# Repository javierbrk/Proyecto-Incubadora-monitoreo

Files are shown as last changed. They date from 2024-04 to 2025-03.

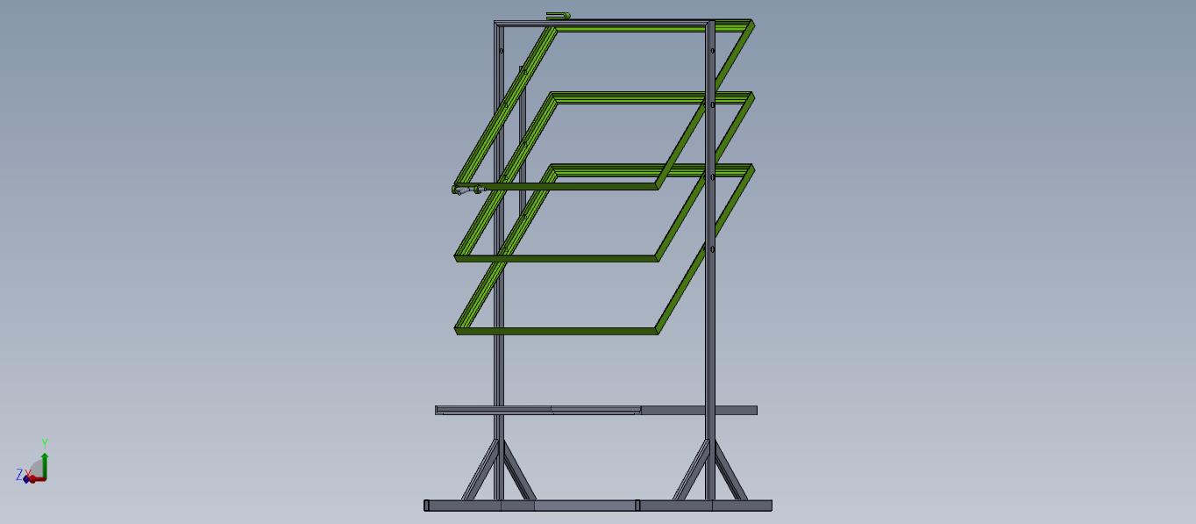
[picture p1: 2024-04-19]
HardWare/ModelosMecanica/SistemaBasculante.jpg

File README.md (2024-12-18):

# LibrePollo

Is an innovative project aimed at enhancing the efficiency and productivity of poultry incubators in family farming. Developed by Asociación Civil AlterMundi and CTO, this system integrates advanced monitoring and control technologies to optimize temperature and humidity levels, reducing manual labor and increasing hatch rates. Utilizing free hardware and software, the project promotes sustainable agricultural practices and empowers local communities with technical skills. Join us in revolutionizing family farming with technology!

## made with :heart: by:

<p align="center" width="100%">
    
</p>

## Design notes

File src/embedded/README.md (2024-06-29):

# Project-Incubadora Software

## Notes before you start :raised_back_of_hand:

 add the current user to the dialout group. This will allow us to use the USB directly

```bash
sudo usermod -a -G dialout $USER
```
We also add ourselves to the group temporarily so we don't have to log in to the system again. If we do not, it will be necessary to restart for the changes to take effect.

```bash
newgrp dialout
```

if you are usign ubuntu 22 and the esp32cam motherboard based on "ID 1a86:7523 QinHeng Electronics CH340 serial converter" you won't be able to use the device. This happens because of conflict between product IDs (a Braille screen reader and my CH340 based chip). Here is the solution :

Edit /usr/lib/udev/rules.d/85-brltty.rules; Search for this line and comment it out:

```bash
ENV{PRODUCT}=="1a86/7523/*", ENV{BRLTTY_BRAILLE_DRIVER}="bm", GOTO="brltty_usb_run"
```

then reboot.

## Firmware with lua support

 clone the repository

```bash
git clone --branch dev-esp32 --depth=1 --shallow-submodules --recurse-submodules https://github.com/nodemcu/nodemcu-firmware.git firmwareESP32 
```
 Once cloned enter the downloaded file with:

```bash
 cd firmwareESP32
```
then download the sdkmanager file to be able to compile the firmware:

```bash
 wget -c https://cutt.ly/QwjY9Sdt --output-document sdkconfig --show-progress
```
```bash
git pull
```
```bash
./install.sh
```
```bash
make menuconfig  
```

```bash
make -j4  
```

## Burn Firmware with ESPTool

__Installation of ESPTool__

```bash
sudo apt install esptool
```

Put the ESP32 in programming mode by holding the IO0 button and pressing the RST button at the same time.

from the 'build' folder run:

```bash
esptool --chip esp32 --port /dev/ttyUSB0 --baud 921600 --before default_reset --after hard_reset write_flash -z --flash_mode dio --flash_freq 80m --flash_size detect 0x1000 bootloader/bootloader.bin 0x10000 NodeMCU.bin 0x8000 partitions.bin
```
or
```bash
make flash
```

## Load the Lua scripts

To load the scripts we have 2 options:
* [EspLorer](https://github.com/4refr0nt/ESPlorer)
* [nodemcu-uploader](https://pypi.org/project/nodemcu-uploader/)

## Editing Lua scripts
* [ZeroBrane](https://studio.zerobrane.com/)
* VSCodium... remember to install sumneko's Lua package, then using the open addon manager install esp32 definitions. 

## Option 1 (ESPlorer, must be latest version)
* [Link to git and readme for the latest version of ESPlorer](https://github.com/4refr0nt/ESPlorer)

 clone the repository:

```bash
git clone https://github.com/4refr0nt/ESPlorer.git
```
after cloning it:

```bash
cd ESPlorer
./mvnw clean package
```
to execute ESPlorer:

```bash
java -jar target/ESPlorer.jar
```

## Option 2 (nodemcu-uploader)

installation:

```bash
sudo pip install nodemcu-uploader
```
once installed, we can upload files using:

```bash
nodemcu-uploader upload init.lua
```

to see the different commands that can be used:
```bash
nodemcu-uploader -h
```

## Option 3 (ZeroBraneStudio)

installation:
```bash
wget https://download.zerobrane.com/ZeroBraneStudioEduPack-1.90-linux.sh
```
After downloading, we give it execution permission with:

```bash
chmod +x ZeroBraneStudioEduPack-1.90-linux.sh
```
after giving it permissions, run the installer:

```bash
./ZeroBraneStudioEduPack-1.90-linux.sh
```

## Useful Links

* [Pad incubadora](https://pad.codigosur.org/AM_Proyecto_Incubadora)
* [Sensor information BME280](https://3iinc.xyz/blog/how-to-use-i2c-sensor-bme280-with-esp32cam/)
* [Documentation nodemcu](https://nodemcu.readthedocs.io/en/dev-esp32)
* [Repository with modules Lua](https://github.com/novalabsxyz/api-examples/blob/master/script/bme280/bme280.lua)
* [Sensor information DHT22](https://nodemcu.readthedocs.io/en/dev-esp32/modules/dht/#dhtread2x)
* [Git Tutorials](https://rogerdudler.github.io/git-guide/index.es.html )
* [Files and photos](https://nube.altermundi.net/s/3arPqaHxs763pmB?path=%2F)

## files we need to send to the ESP32

1. bmw280.lua located in the libs folder 
2. credentials.lua located in the libs folder (in lines 5 and 6 you have to write your SSID and password)
3. wifiinit.lua located in the app folder 
4. SendToGrafana.lua located in the app folder

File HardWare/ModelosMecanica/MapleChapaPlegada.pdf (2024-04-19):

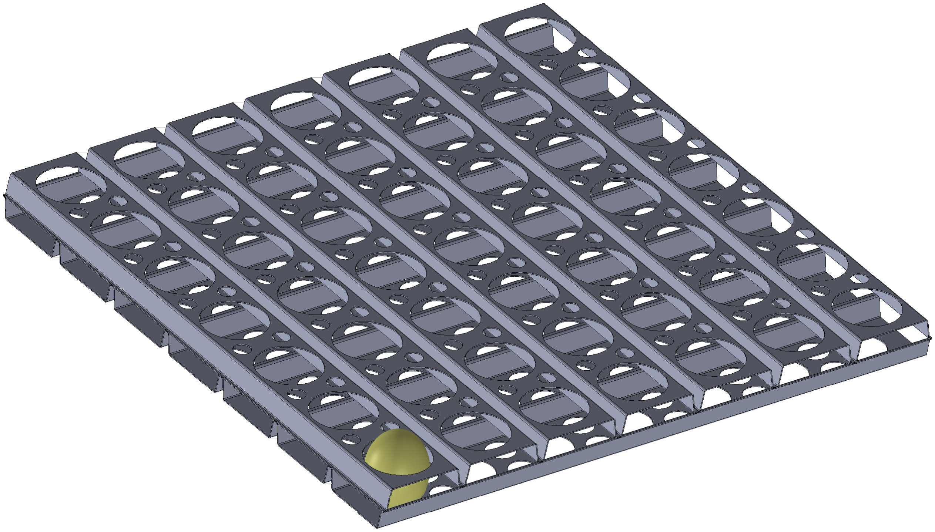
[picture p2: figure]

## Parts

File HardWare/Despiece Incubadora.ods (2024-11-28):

módulo | item | cantidad por incu | enlace
Electronica electriciad
 | 1 Enchufe macho | 1 | https://articulo.mercadolibre.com.ar/MLA-1508200684-pack-x10-enchufe-ficha-macho-10a-3-patas-negro-_JM |  | 7700 | 7700
 | 2m + 1m cable TPR 3 x 2,5mm | 3
 | 2 Prensa-cables 10mm | 2 | https://articulo.mercadolibre.com.ar/MLA-1127213017-pack-x10-prensacable-diametro-cable-5-10mm-ip68-pg11-34-_JM |  | 8.804 | 8.804
 | 1 Disyuntor diferencial 16A (https://www.mercadolibre.com.ar/disyuntor-diferencial-bipolar-16a-2x16a-10ma-usensible-sica/p/MLA10763521) | 1 | https://www.mercadolibre.com.ar/disyuntor-diferencial-2x25-sica-bipolar-monofasico/p/MLA21622049 | https://www.mercadolibre.com.ar/disyuntor-diferencial-bipolar-16a-2x16a-10ma-usensible-sica/p/MLA10763522 | 23000 | 23000
 | Alimentación barril a PCB (https://tienda.ityt.com.ar/plug-alimentacion/3471-lote-10-x-plug-dc-55x21mm-conector-alimentaci%C3%B3n-itytarg.html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) | 1 |  |  |  | 0
 | Térmica 5A (https://www.mercadolibre.com.ar/interruptor-automatico-miniatura-para-riel-din-sica-limit-782105/p/MLA11259424) | 1 | https://www.mercadolibre.com.ar/interruptor-automatico-miniatura-para-riel-din-sica-limit-782105/p/MLA11259424 |  | 2500 | 2500
 | Térmica 1 A (https://www.mercadolibre.com.ar/interruptor-automatico-miniatura-para-riel-din-sica-limit-782105/p/MLA11259424) | 2 | https://articulo.mercadolibre.com.ar/MLA-1410464619-termica-unipolar-termomagnetica-1a-1x1-sica-782101-_JM | https://articulo.mercadolibre.com.ar/MLA-1364995926-termica-unipolar-termomagnetica-1a-1x1-sica-782101-_JM | 4000 | 8000
 | PCB Olivia | 1
 | Fuente 12V 5A (https://articulo.mercadolibre.com.ar/MLA-1948645246-fuente-metalica-de-alimentacion-12-v-5a-_JM) | 1 | https://articulo.mercadolibre.com.ar/MLA-1948645246-fuente-metalica-de-alimentacion-12-v-5a-_JM |  | 7000 | 7000
 | Step-Down 6V (https://articulo.mercadolibre.com.ar/MLA-723761124-fuente-step-down-dc-dc-lm2596-125v-35v-3a-arduino-nubbeo-_JM) | 1 | https://articulo.mercadolibre.com.ar/MLA-723761124-fuente-step-down-dc-dc-lm2596-125v-35v-3a-arduino-nubbeo-_JM |  |  | 0
Conexiones | Alimentación Step-down 6v a PuenteH y Relé | 1
Conexiones | Sensor BME280 (4pin) (https://articulo.mercadolibre.com.ar/MLA-818527025-sensor-modulo-arduino-bme280-temperatura-humedad-presion-_JM) | 1
Conexiones | FC Up (2pin) | 1
Conexiones | FC Down (2pin) | 1
Conexiones | PuenteH (4 pin) | 1
Conexiones | Módulo Relé (3pin) | 1
 | Cablecanal (https://articulo.mercadolibre.com.ar/MLA-918107217-cable-canal-autoadhesivo-taad-20x10-x-10-mts-_JM) | 1 | https://articulo.mercadolibre.com.ar/MLA-918107217-cable-canal-autoadhesivo-taad-20x10-x-10-mts-_JM |  |  | 0
 | CAJA Estanco (https://www.mercadolibre.com.ar/caja-estanca-plastica-210x310x110-mm-blanca-ip65-color-blanco/p/MLA26881998) | 1 | https://www.mercadolibre.com.ar/caja-estanca-plastica-210x310x110-mm-blanca-ip65-color-blanco/p/MLA26881998 |  | 16000 | 16000
 | Puente H | 1
 | Regleta neutros | 1 | https://articulo.mercadolibre.com.ar/MLA-1213323854-pack-x6-bornera-distrib-repartidor-fase-neutra-tierra-7x6mm-_JM |  |  | 0
 | Interruptor Iluminación | 1
 | Sensor BME280 (https://articulo.mercadolibre.com.ar/MLA-818527025-sensor-modulo-arduino-bme280-temperatura-humedad-presion-_JM) | 1 | https://articulo.mercadolibre.com.ar/MLA-818527025-sensor-modulo-arduino-bme280-temperatura-humedad-presion-_JM |  | 10300 | 10300
Humedad |  |  |  |  |  | 0
 | bomba de nafta | 8 | https://articulo.mercadolibre.com.ar/MLA-1662031398-bomba-de-nafta-tbosch-corsa-meriva-gol-suran-siena-fiat-uno-_JM |  | 17000 | 136000
 | picos asperción x 3 | 3 | https://listado.mercadolibre.com.ar/pico-metalico_CustId_7317189_NoIndex_True |  | 32000 | 96000
 | acoples rápido | 8 | https://articulo.mercadolibre.com.ar/MLA-906924217-conector-rapido-neumatico-recto-tubo-tubo-de-6-mm-a-8-mm-_JM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 |  | 3560 | 28480
 | Budineras | 8 | https://articulo.mercadolibre.com.ar/MLA-849023158-budinera-budin-ingles-flanera-aluminio-34cm-pettish-online-_JM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 |  | 10000 | 80000
 | alumnio 3mm | 8 |  |  |  | 0
 | espiga | 8 |  |  |  | 0
 | yerbera
 | manguera 8mm
 | salida de tanque | 8 |  |  |  | 0
 | Flotante | 8 | https://articulo.mercadolibre.com.ar/MLA-1313921621-flotante-compacto-tanque-agua-12-flux-_JM?quantity=4 |  | 9000 | 72000
Rotación |  |  |  |  |  | 0
 | Estructura hierro |  |  |  |  | 0
 | anclajes a la estructura (bulon pasante con dos tuercas para regular la distancia y tornillos para )
 | Bulones pasantes
 | Motor
 | soporte 3d motor, soporte, polea
 | Contrapeso
 | Cinta gross
 | sensores | 16 | https://articulo.mercadolibre.com.ar/MLA-878544727-sensor-magnetico-para-alarma-puerta-y-ventana-seguridad-_JM |  | 3000 | 48000
Accesorios |  |  |  |  |  | 0
 | resistencia | 8 | https://articulo.mercadolibre.com.ar/MLA-913198984-resistencia-para-incubadora-de-huevos-electrica-200w-220v-_JM |  | 140000 | 1120000
 | Luz | 7 | https://articulo.mercadolibre.com.ar/MLA-862597264-reflector-led-10w-luz-fria-apto-exterior-800lm-_JM |  | 3200 | 22400
 | L para el ventilador |  |  |  |  | 0
 | ventilador | 8 | https://articulo.mercadolibre.com.ar/MLA-603230889-turbina-cooler-extractor-fan-220v-ruleman-6-pulgadas-_JM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 |  | 29000 | 232000
 | Bandejas hueveras | 30 |  |  | 4000 | 120000
 | Bandejas nacedoras | 8 |  |  | 2000 | 16000
 | maples plásticos | 60 |  |  | 4000 | 240000
 | sunchos |  |  |  |  | 0
 | tejido alambre | 20 |  |  | 15909 | 318180
Carcasa |  |  |  |  |  | 2539360
 | Placas
 | pintura
 | sellador y pegamento
 | tornillos
 | perfilería aluminio
 | Bisagras
 | tarugos, tornillos y otros
 | patas
 | Bisagras
 | Ventana vertical
 | Patas de goma/esquinero

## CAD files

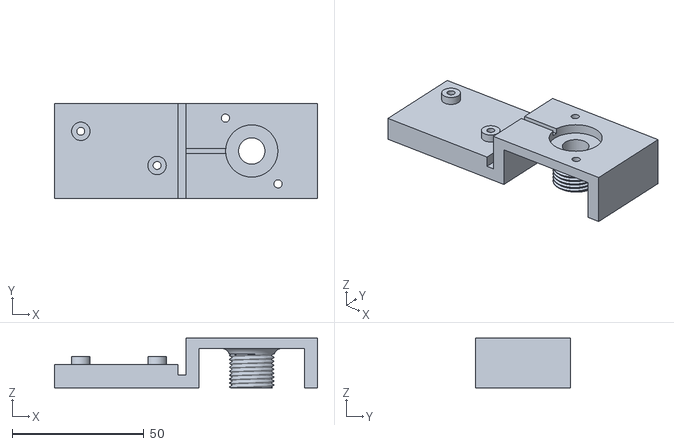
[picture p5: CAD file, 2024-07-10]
HardWare/modelos3D/humidificador/estructura_principal_humidificador.stl
100.0 x 36.0 x 19.0

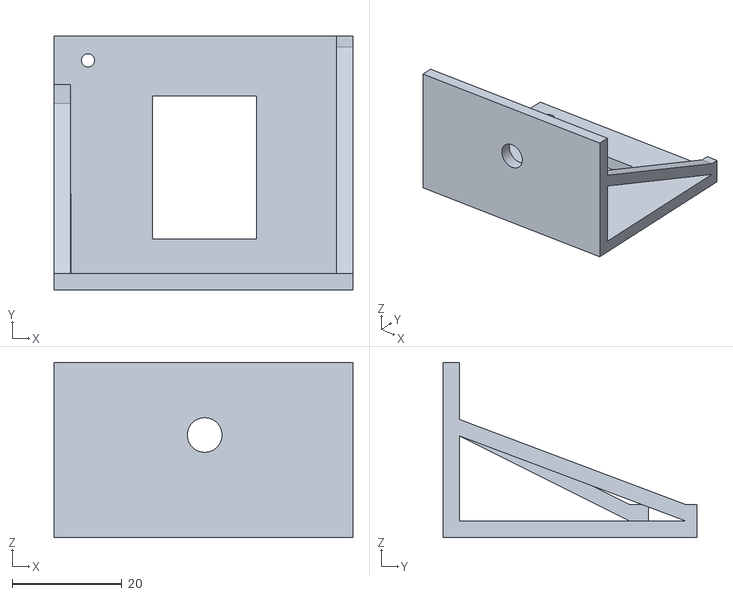
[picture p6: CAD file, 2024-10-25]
HardWare/modelos3D/rotacion/CarcasaPolea_conColumnas.stl
54.5 x 46.3 x 31.9

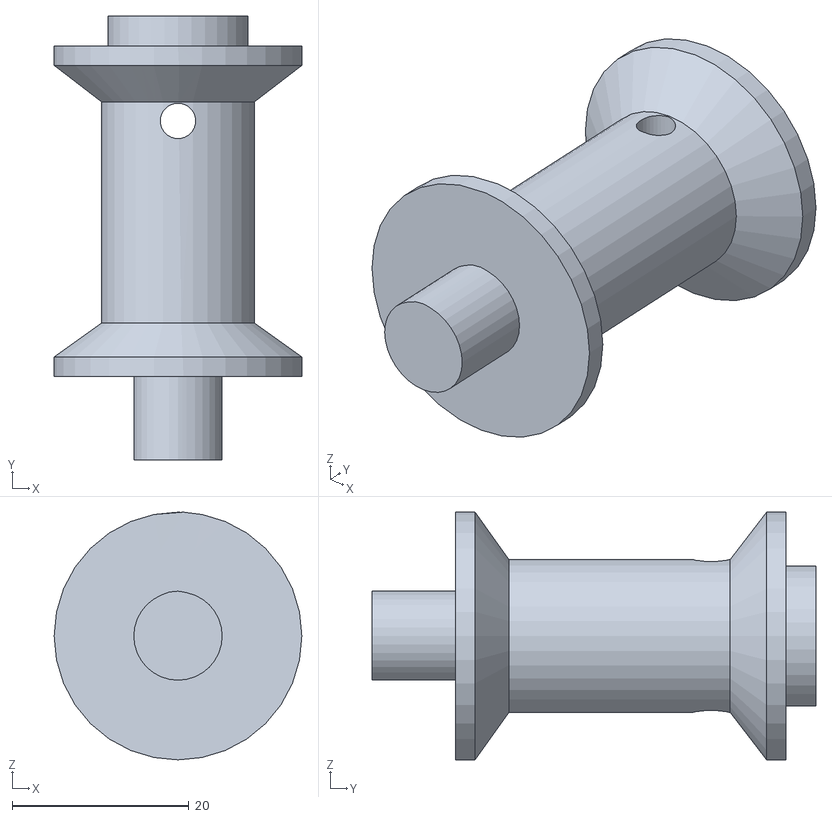
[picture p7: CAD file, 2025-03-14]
HardWare/modelos3D/rotacion/modelos-finales/Polea.stl
28.1 x 50.3 x 28.1

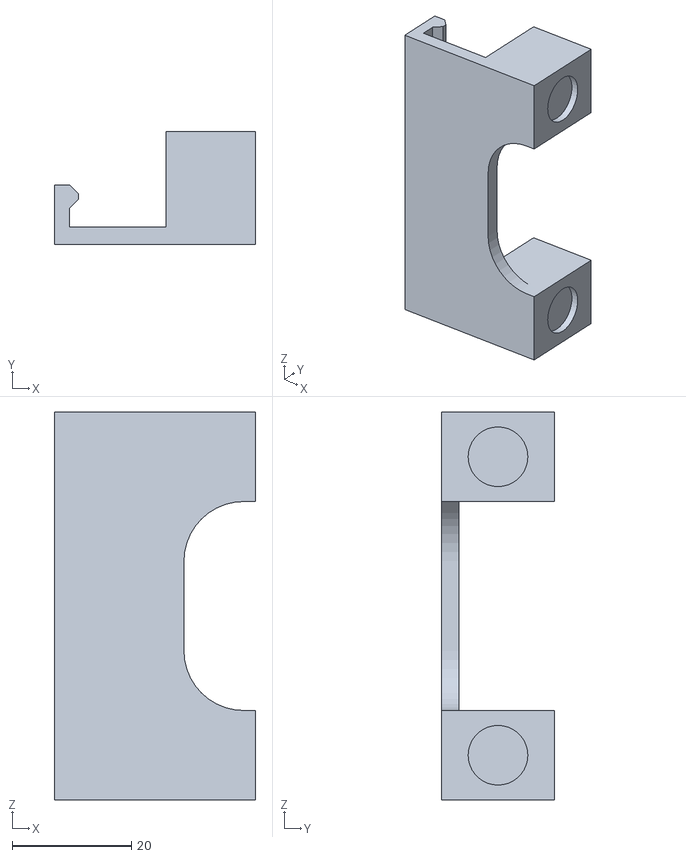
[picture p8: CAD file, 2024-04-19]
HardWare/modelos3D/SoporteIman.STL
33.7 x 19.0 x 65.0

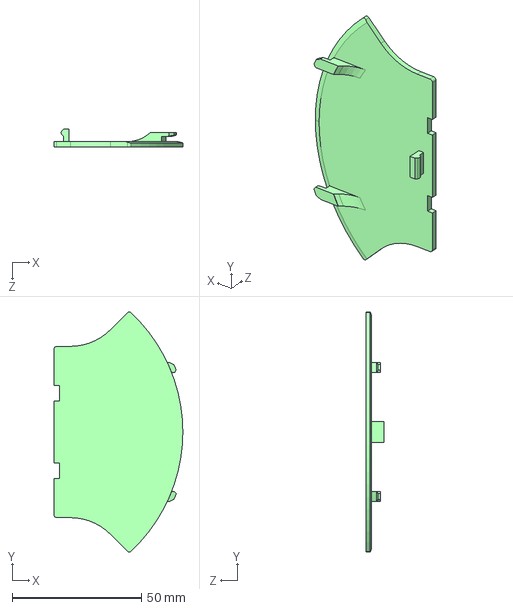
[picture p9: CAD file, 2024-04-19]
HardWare/ModelosMecanica/EnSTEP/SoporteEfectoHallTapa.STEP
49.9 x 93.0 x 6.80 mm

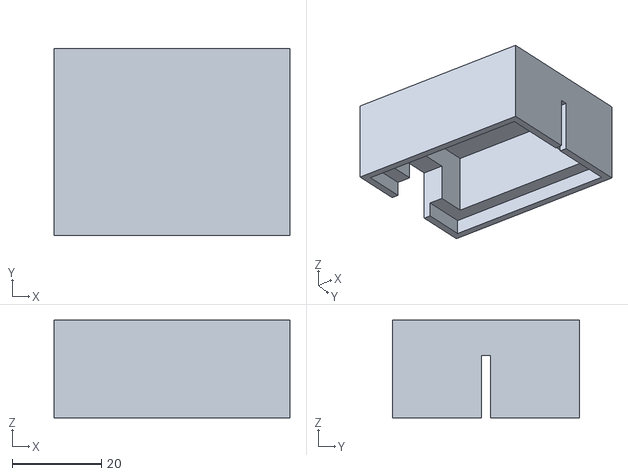
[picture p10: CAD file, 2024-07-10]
HardWare/modelos3D/humidificador/caja_protectora_humidificador.stl
53.0 x 42.0 x 22.0

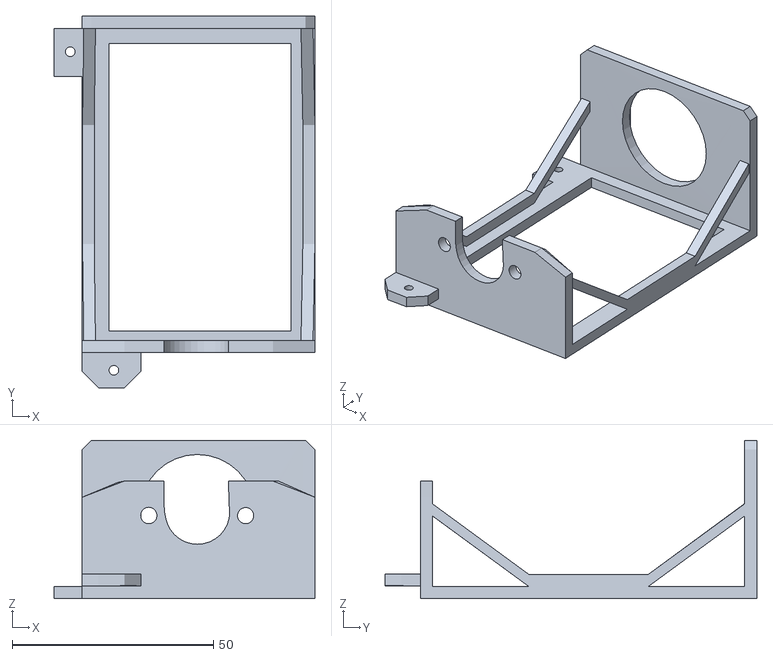
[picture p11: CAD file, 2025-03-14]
HardWare/modelos3D/rotacion/modelos-finales/SoporteMotor.stl
64.8 x 92.4 x 39.4

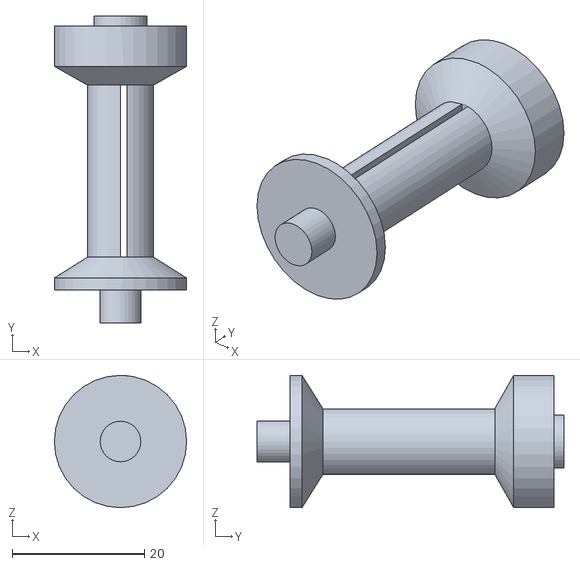
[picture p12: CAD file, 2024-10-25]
HardWare/modelos3D/rotacion/SoportePoleaNuevo.stl
20.0 x 46.5 x 20.0

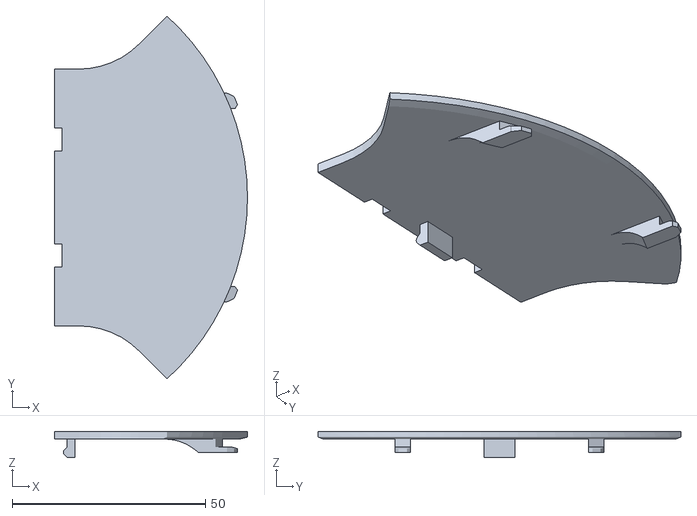
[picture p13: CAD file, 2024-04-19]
HardWare/modelos3D/SoporteEfectoHallTapa.STL
49.9 x 93.8 x 6.80

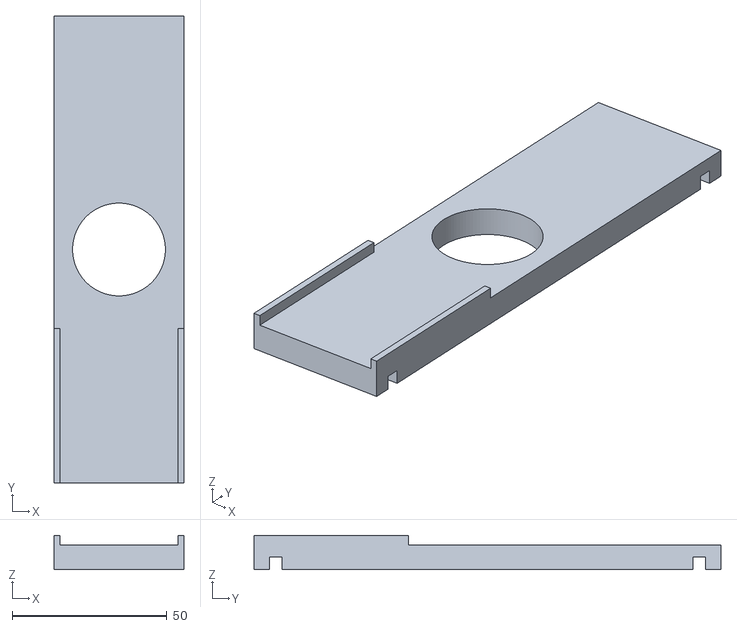
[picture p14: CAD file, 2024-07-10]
HardWare/modelos3D/humidificador/soporte_humidificador.stl
42.0 x 151.0 x 11.0

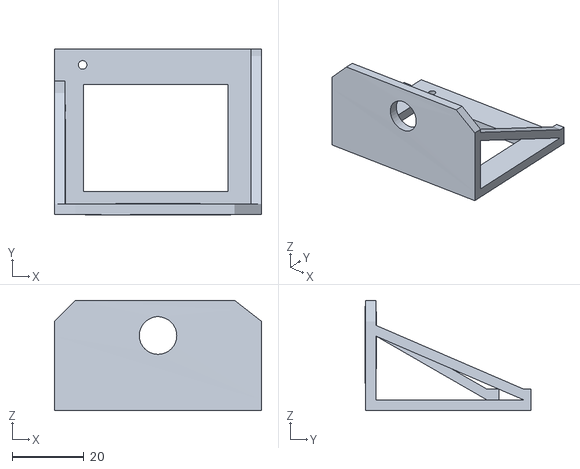
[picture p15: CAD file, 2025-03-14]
HardWare/modelos3D/rotacion/modelos-finales/SoportePolea.stl
57.8 x 46.3 x 30.8

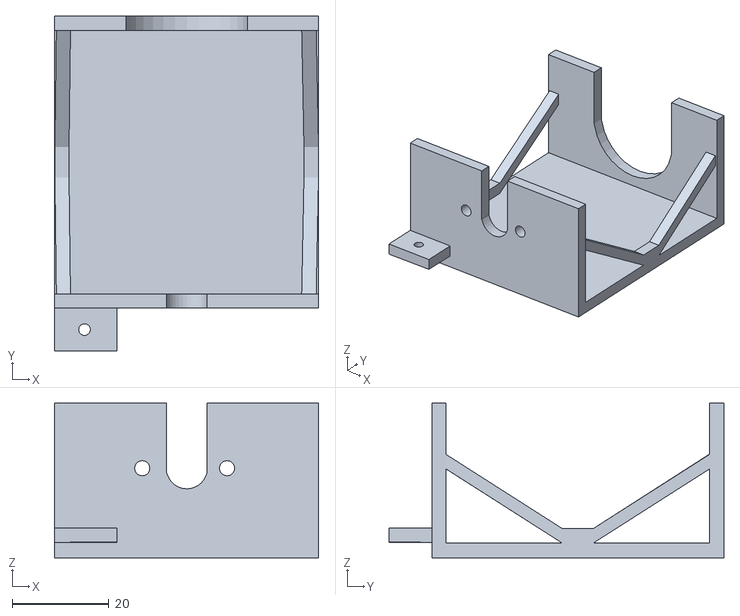
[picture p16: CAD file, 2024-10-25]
HardWare/modelos3D/rotacion/SoporteMotorConTriangulos.stl
54.5 x 69.1 x 31.9

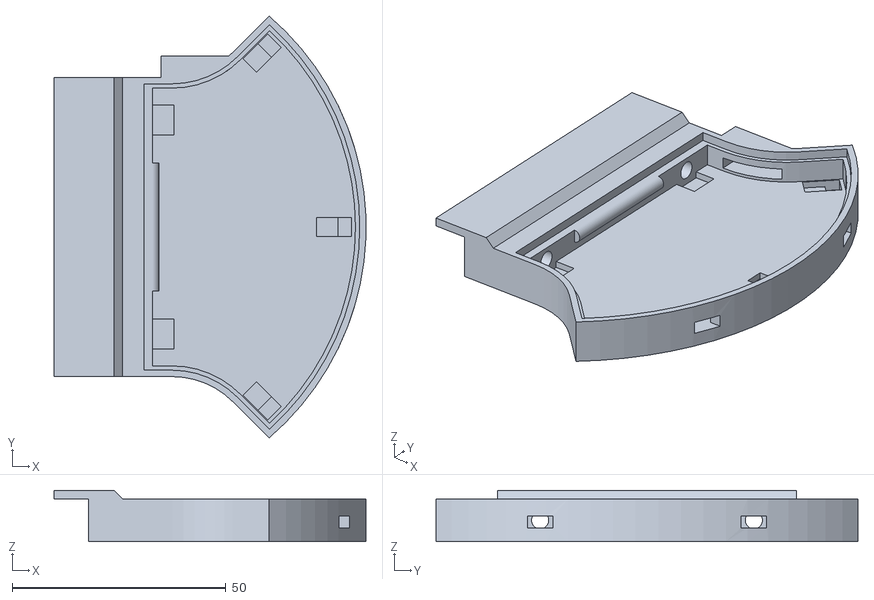
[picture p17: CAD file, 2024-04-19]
HardWare/modelos3D/SoporteEfectoHall.STL
72.9 x 98.7 x 12.0

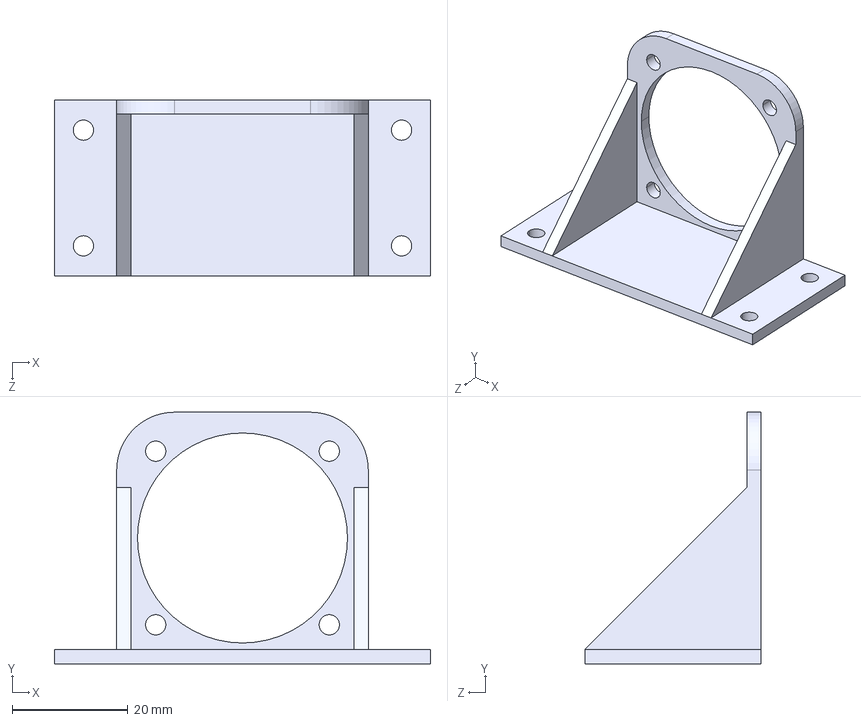
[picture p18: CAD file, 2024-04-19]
HardWare/ModelosMecanica/EnSTEP/SoporteCooler.STEP
65.0 x 43.5 x 30.5 mm

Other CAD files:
HardWare/modelos3D/humidificador/soporte_sensor_humidificador.stl
HardWare/modelos3D/SoporteImanTransversal.STL
HardWare/ModelosMecanica/EnSTEP/SoporteMotorGiraplatoSinPolea.STEP
HardWare/ModelosMecanica/EnSTEP/CableCanalSoporteReedSwitch.STEP
HardWare/ModelosMecanica/EnSTEP/PoleaMotorGiraplatoGrande.STEP
HardWare/ModelosMecanica/EnSTEP/SoporteEfectoHall.STEP
HardWare/ModelosMecanica/EnSTEP/SoporteHumidificador.STEP
HardWare/modelos3D/CableCanalSoporteReedSwitch.STL
HardWare/modelos3D/FinalCorrea.STL
HardWare/modelos3D/PoleaMotorGiraplatoGrande.STL
HardWare/modelos3D/SoporteCooler.STL
HardWare/modelos3D/SoporteHumidificador.STL
HardWare/modelos3D/SoporteMotorGiraplatoSinPolea.STL
HardWare/modelos3D/humidificador/Tubo_humidificador.stl

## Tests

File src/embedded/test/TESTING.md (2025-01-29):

# Testing guide

LibrePollo has unit tests that help us add new features while keeping maintenance effort contained.

We encourage contributors to write [tests](https://en.wikipedia.org/wiki/Unit_testing)  when adding new functionality and also while fixing [regressions](https://en.wikipedia.org/wiki/Regression_testing).

LibreMesh unit testing is based in the powerful [busted](https://lunarmodules.github.io/busted/) library which has a very good documentation.

## Install required sofotware
```
apt-get install luarocks
sudo luarocks install --server=https://luarocks.org/dev ltn12
sudo luarocks install luasockets
sudo luarocks install busted
sudo luarocks install json-lua 
sudo luarocks install inspect
```
## How to run the tests

Just execute `busted test_*` inside test folder.

## Testing directory structure

Test files for source module `foo.lua` live inside a `test` directory with its names begining with `test_`:

```
test/test_foo.lua

```

Testing utilities, fake libraries and integration tests live inside a root `test/` directory:

```
tests/test_some_integration_tests.lua
tests/test_other_general_tests.lua
tests/fake/bazlib.lua
tests/tests/test_bazlib.lua
```

## How to write tests

Here is a very simple test of a library `foo`:
```[lua]
local foo = require 'foo'

describe('foo library tests', function()
    it('very simple test of f_sum(a, b)', function()
        assert.is.equal(4, foo.f_sum(2, 2))
        assert.is.equal(2, foo.f_sum(2, 0))
        assert.is.equal(0, foo.f_sum(2, -2))
    end)
end)
```
## manual testing
```lua
dofile('credentials.lua')
```
TODO: Implement as a post-power-on self-test or in a app command

### Test Rotation


We are using motor A inputs. So the first thing to test is the digital inputs.
Leave  a jumper in EN_A like the picture and remove the jumper from EN_B.
Use the other pin from EN_B witch should be in a logical 1 state to activate "in 1" first and then "in 2". Just conect a Female to Female wire betwen the pins and watch the engine rotate in both directions. 



Move down:
```lua
-- turn on
gpio.write(GPIOVOLTEO_EN,1)
gpio.write(GPIOVOLTEO_UP,0)
gpio.write(GPIOVOLTEO_DOWN,1)
-- turn off
gpio.write(GPIOVOLTEO_DOWN,0)
```

Move up:
```lua
gpio.write(GPIOVOLTEO_EN,1)
gpio.write(GPIOVOLTEO_DOWN,0)
gpio.write(GPIOVOLTEO_UP,1)
-- turn off
gpio.write(GPIOVOLTEO_UP,0)
```

### Test Sensors
```lua
print(gpio.read(GPIOREEDS_UP), gpio.read(GPIOREEDS_DOWN))
```

When the sensor is near the human, it switches to 0.  
Test both the upper and lower sensors.

### Test Resistor

Turn on:
```lua
gpio.write(GPIORESISTOR,1)
```

Turn off:
```lua
gpio.write(GPIORESISTOR,0)
```

### Test Humidifier

Turn on:
```lua
gpio.write(GPIOHUMID,0)
```

Turn off:
```lua
gpio.write(GPIOHUMID,1)
```

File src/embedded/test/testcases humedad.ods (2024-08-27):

humedad | tiempo (min) | tiempo (sec) | hum | razón
10 | 0 | 0 | true | menor al min
20 | 2 | 120 | true | menor al min
30 | 19 | 1140 | false | mas de 18 min encendido esperar 5 min hasta 24
20 | 22 | 1320 | false | mas de 18 min encendido esperar
10 | 41 | 2460 | true | menor al min
40 | 42 | 2520 | true | menor al min
59 | 43 | 2580 | true | menor al min
61 | 44 | 2640 | true | queda asi sin comando
71 | 45 | 2700 | false | mayor al max
66 | 46 | 2760 | false | queda asi sin comando
55 | 47 | 2820 | true | menor al min
55 | 57 | 3420 | true | menor al min
55 | 66 | 3960 | false | mas de 20 min encendido esperar 5 hasta 71
55 | 69 | 4140 | false | mas de 20 min encendido esperar hasta 86
40 | 71 | 4260 | false | mas de 20 min encendido esperar hasta 86
40 | 87 | 5220 | true | menor al min
66 | 89 | 5340 | true | queda asi sin comando
77 | 90 | 5400 | false | mayor al max
64 | 91 | 5460 | false | queda asi sin comando

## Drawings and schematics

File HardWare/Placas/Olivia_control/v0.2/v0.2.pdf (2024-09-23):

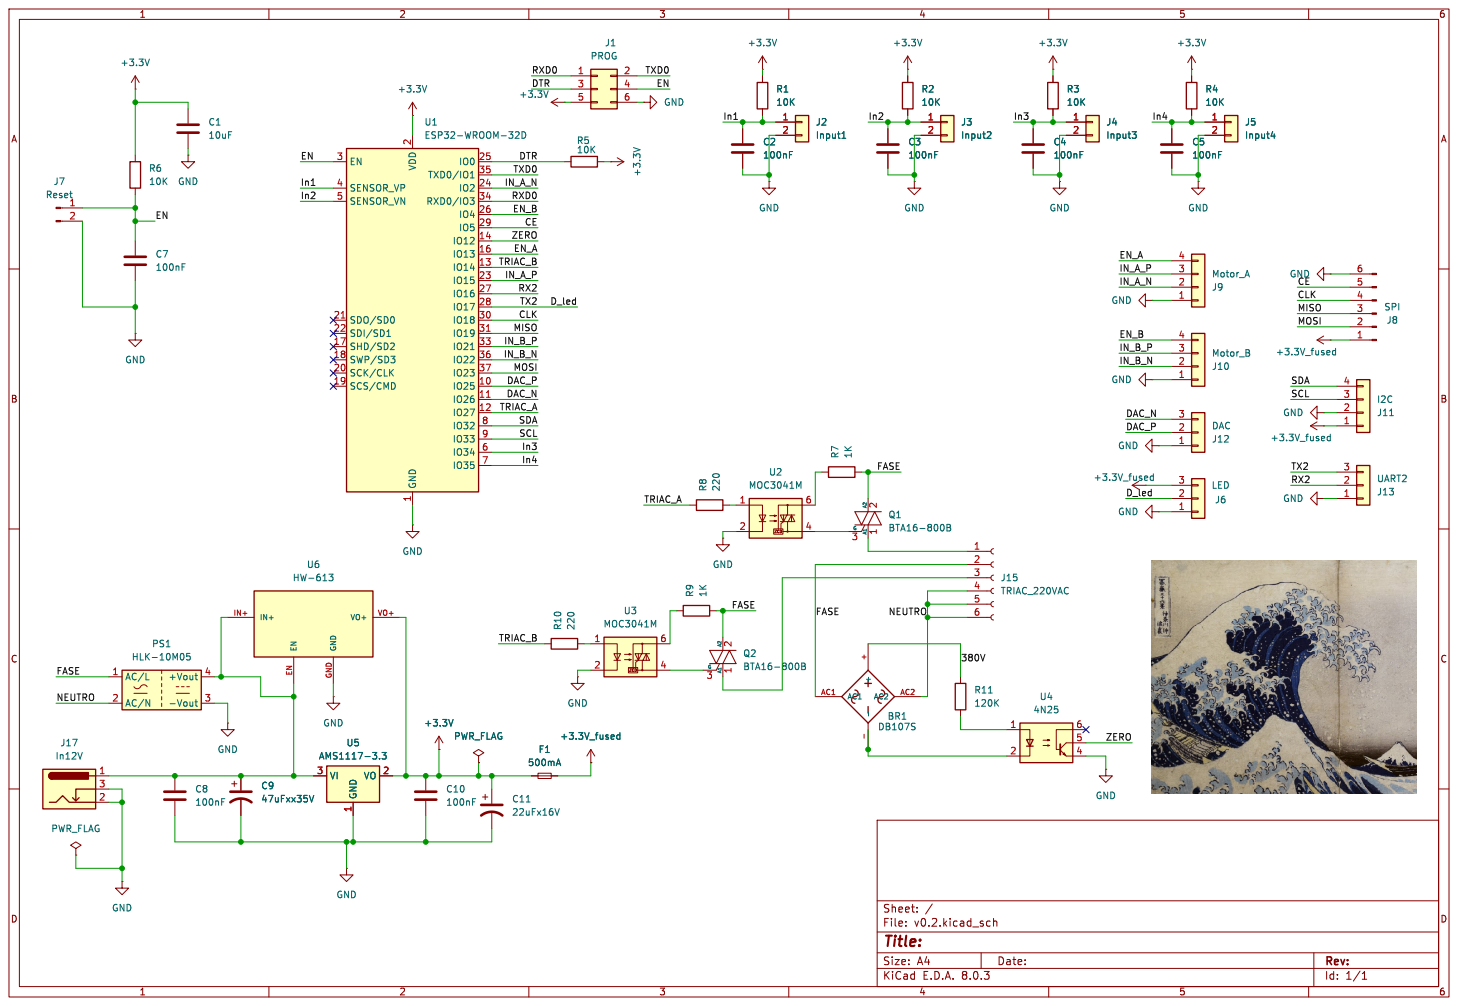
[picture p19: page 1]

2 SCK/CLK 20 SDO/SD0 21 SDI/SD1 22

LED GND GND GND GND

Id: 1/1 Title: File: v0.2.kicad_sch Sheet: /

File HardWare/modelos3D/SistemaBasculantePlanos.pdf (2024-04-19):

E E

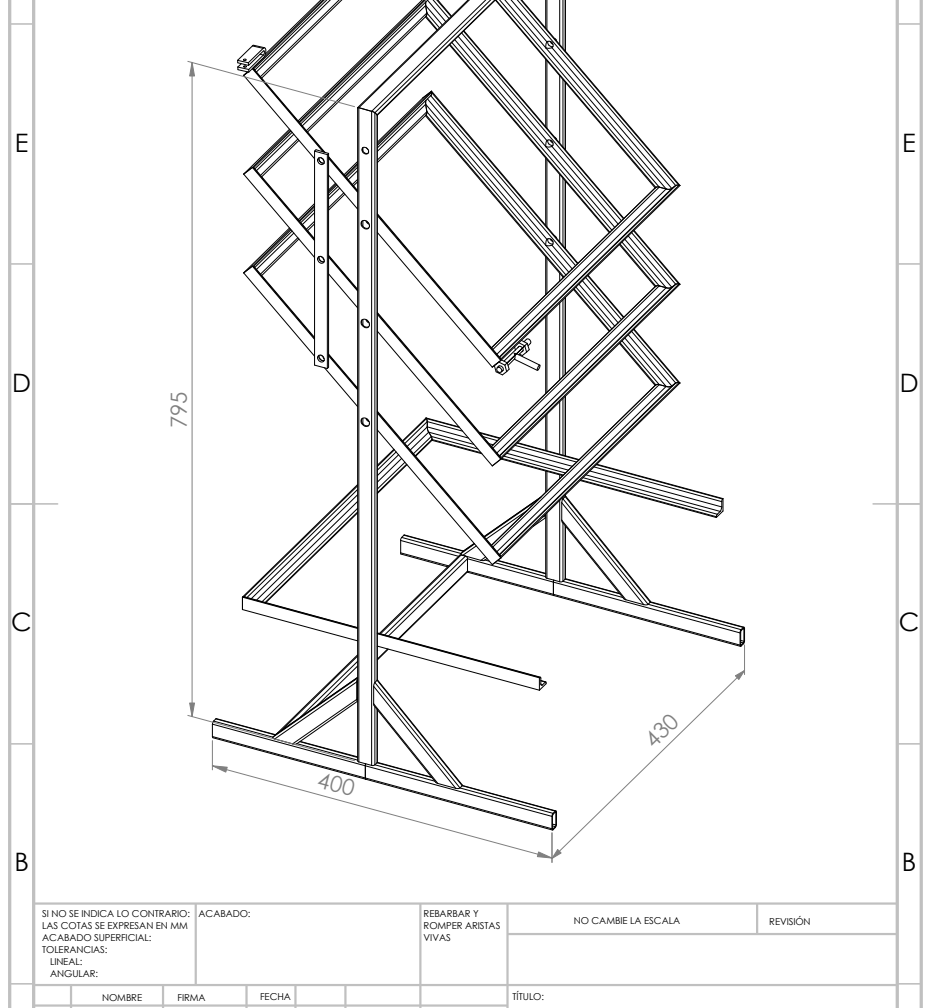
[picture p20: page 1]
ACABADO:; REBARBAR Y; ROMPER ARISTAS VIVAS; NOMBRE; FIRMA; FECHA; NO CAMBIE LA ESCALA; REVISIÓN; TÍTULO:

SI NO SE INDICA LO CONTRARIO:
LAS COTAS SE EXPRESAN EN MM
ACABADO SUPERFICIAL:
TOLERANCIAS:
LINEAL:
ANGULAR:

E E

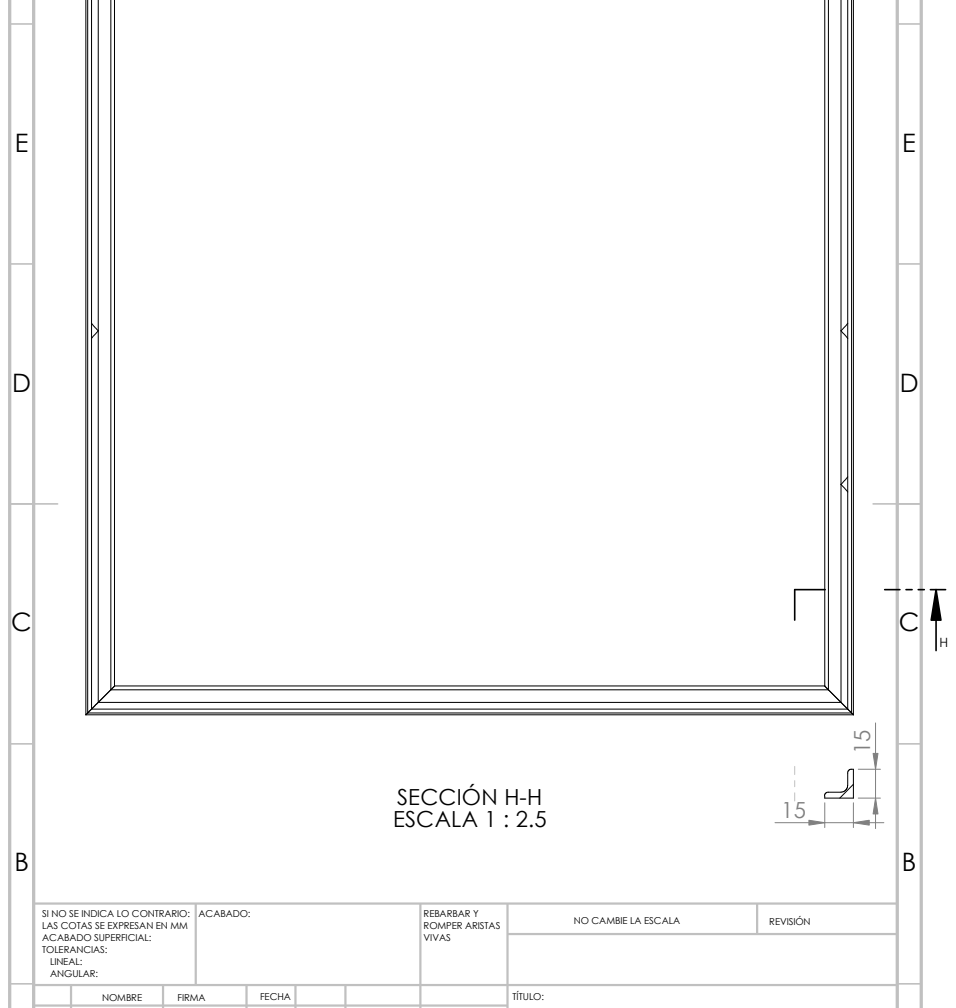
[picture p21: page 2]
ACABADO:; REBARBAR Y; NO CAMBIE LA ESCALA; REVISIÓN; SECCIÓN H-H; ESCALA 1 : 2.5

SI NO SE INDICA LO CONTRARIO:

# 400 ⁷⁹⁵ 120 120 435

E E

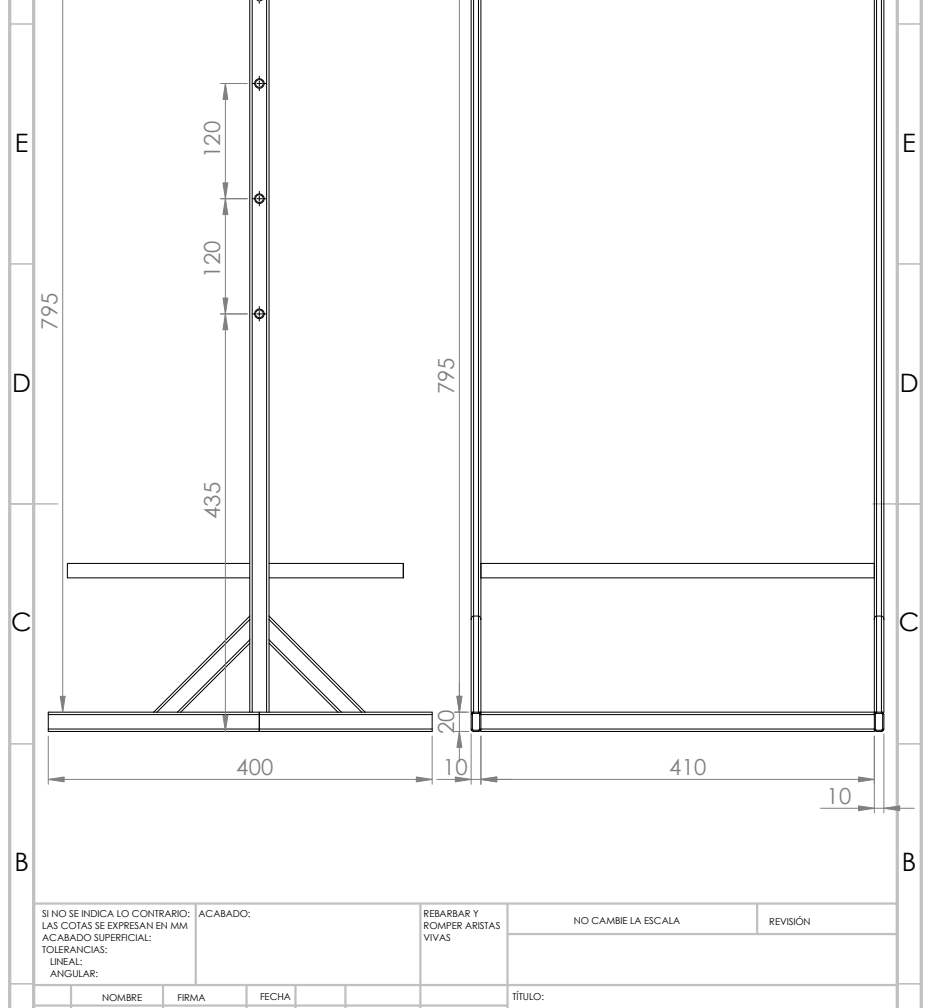
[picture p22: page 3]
10 ²⁰ ⁷⁹⁵; ACABADO:; REBARBAR Y; NO CAMBIE LA ESCALA; REVISIÓN

SI NO SE INDICA LO CONTRARIO:

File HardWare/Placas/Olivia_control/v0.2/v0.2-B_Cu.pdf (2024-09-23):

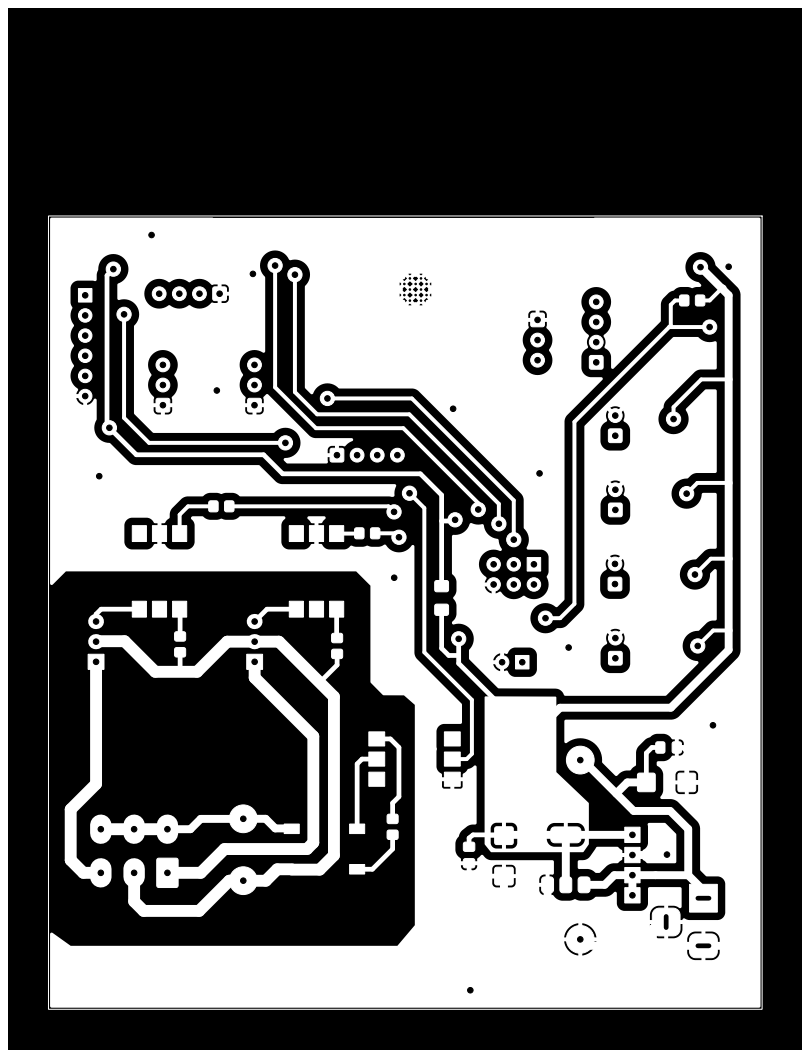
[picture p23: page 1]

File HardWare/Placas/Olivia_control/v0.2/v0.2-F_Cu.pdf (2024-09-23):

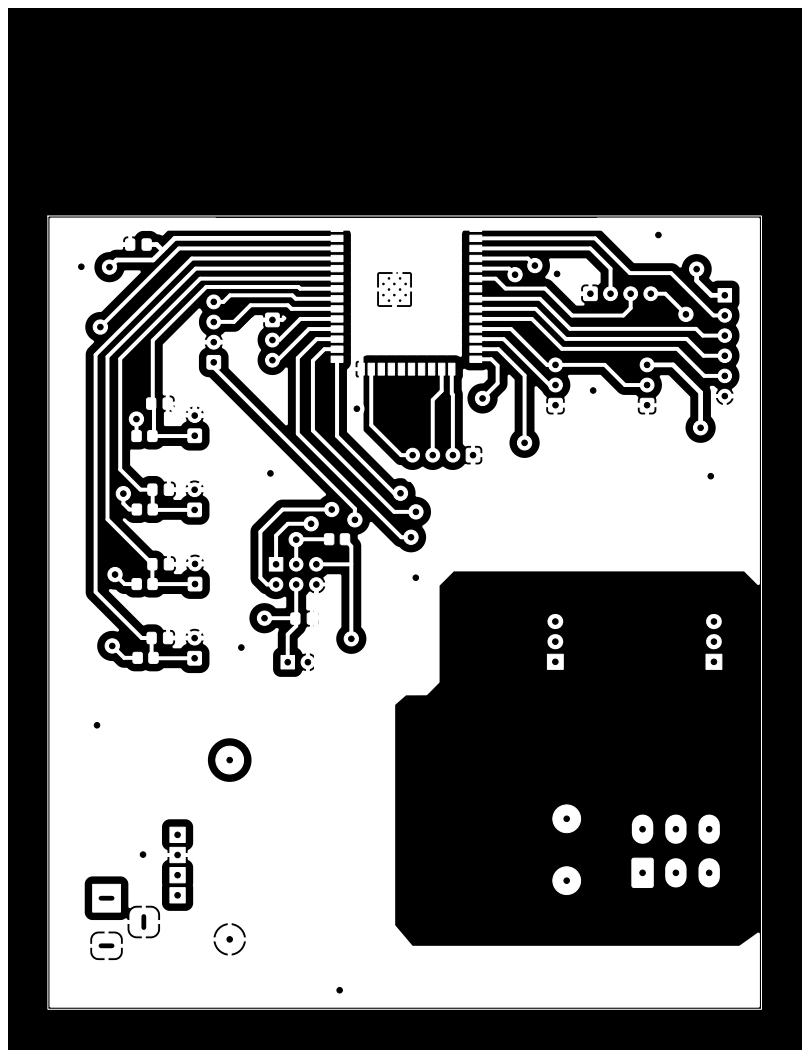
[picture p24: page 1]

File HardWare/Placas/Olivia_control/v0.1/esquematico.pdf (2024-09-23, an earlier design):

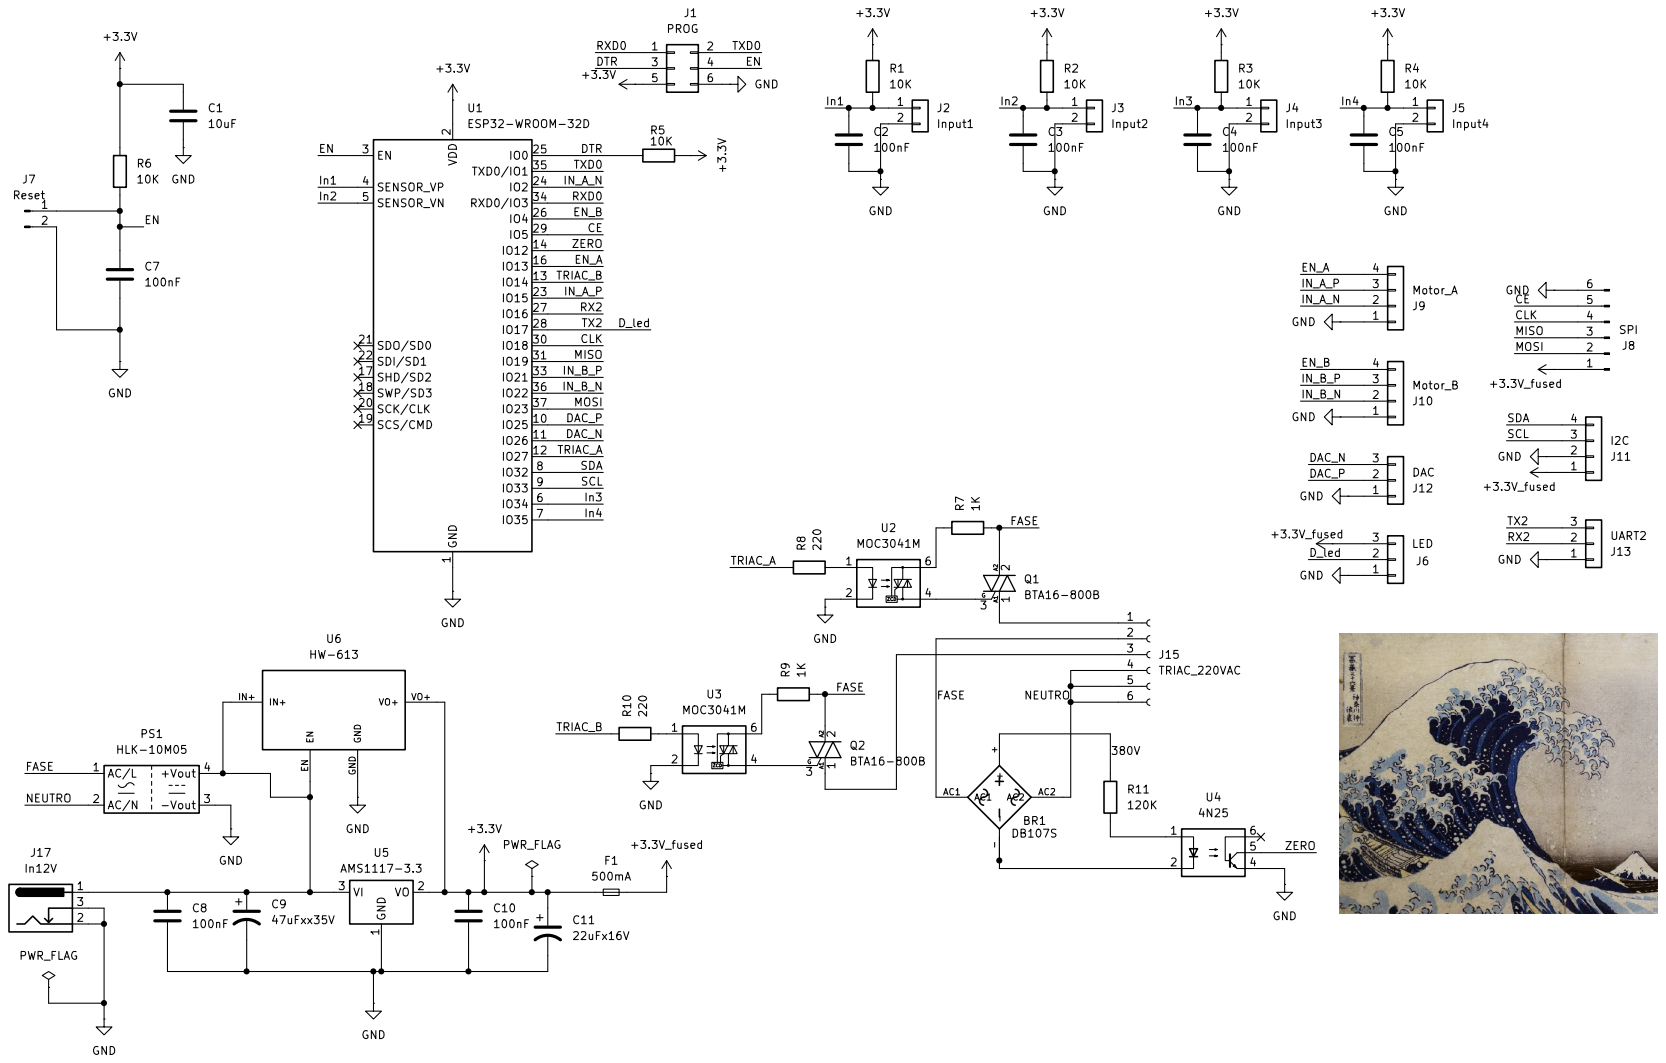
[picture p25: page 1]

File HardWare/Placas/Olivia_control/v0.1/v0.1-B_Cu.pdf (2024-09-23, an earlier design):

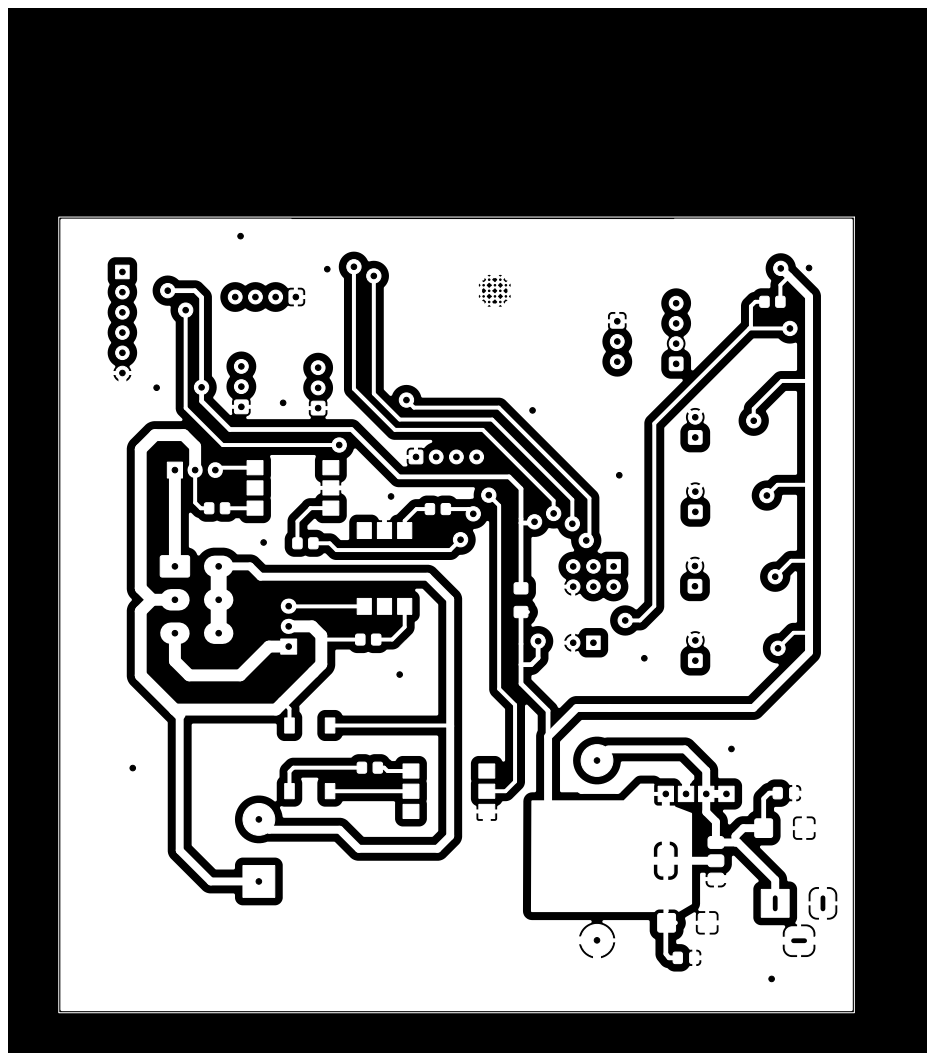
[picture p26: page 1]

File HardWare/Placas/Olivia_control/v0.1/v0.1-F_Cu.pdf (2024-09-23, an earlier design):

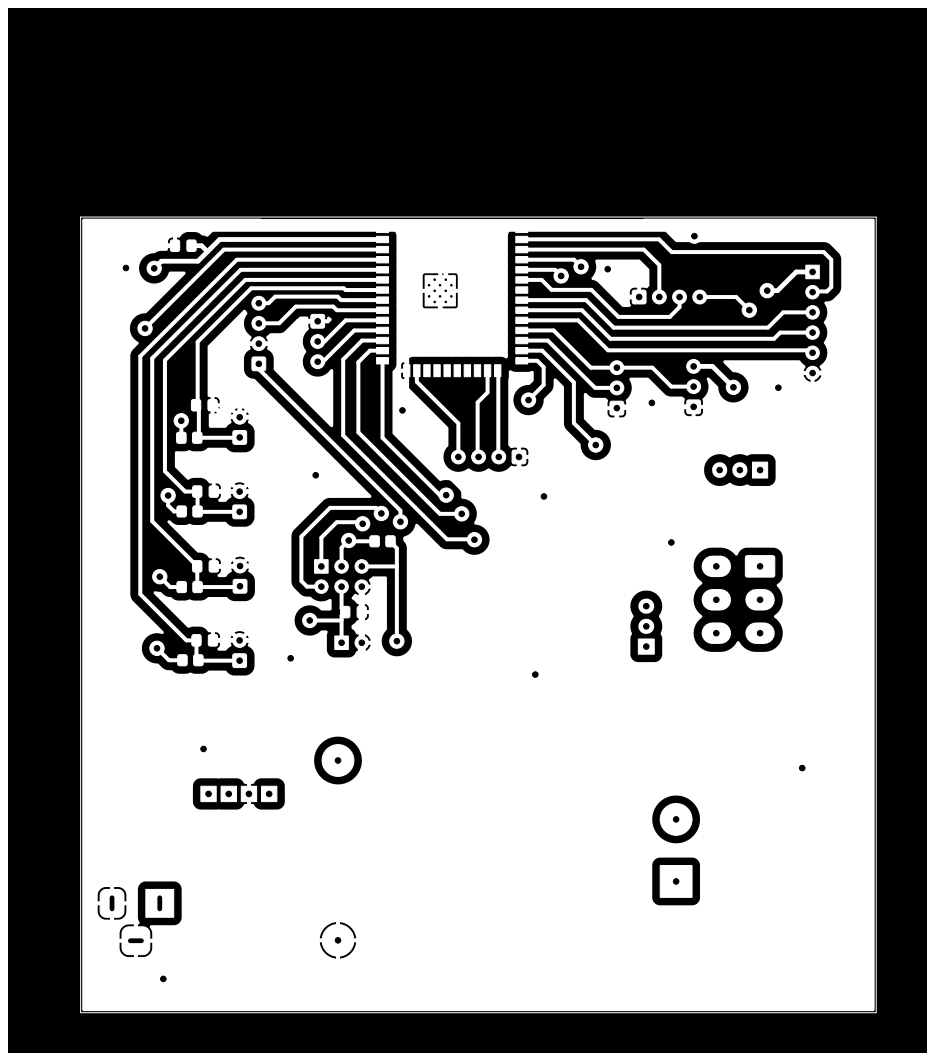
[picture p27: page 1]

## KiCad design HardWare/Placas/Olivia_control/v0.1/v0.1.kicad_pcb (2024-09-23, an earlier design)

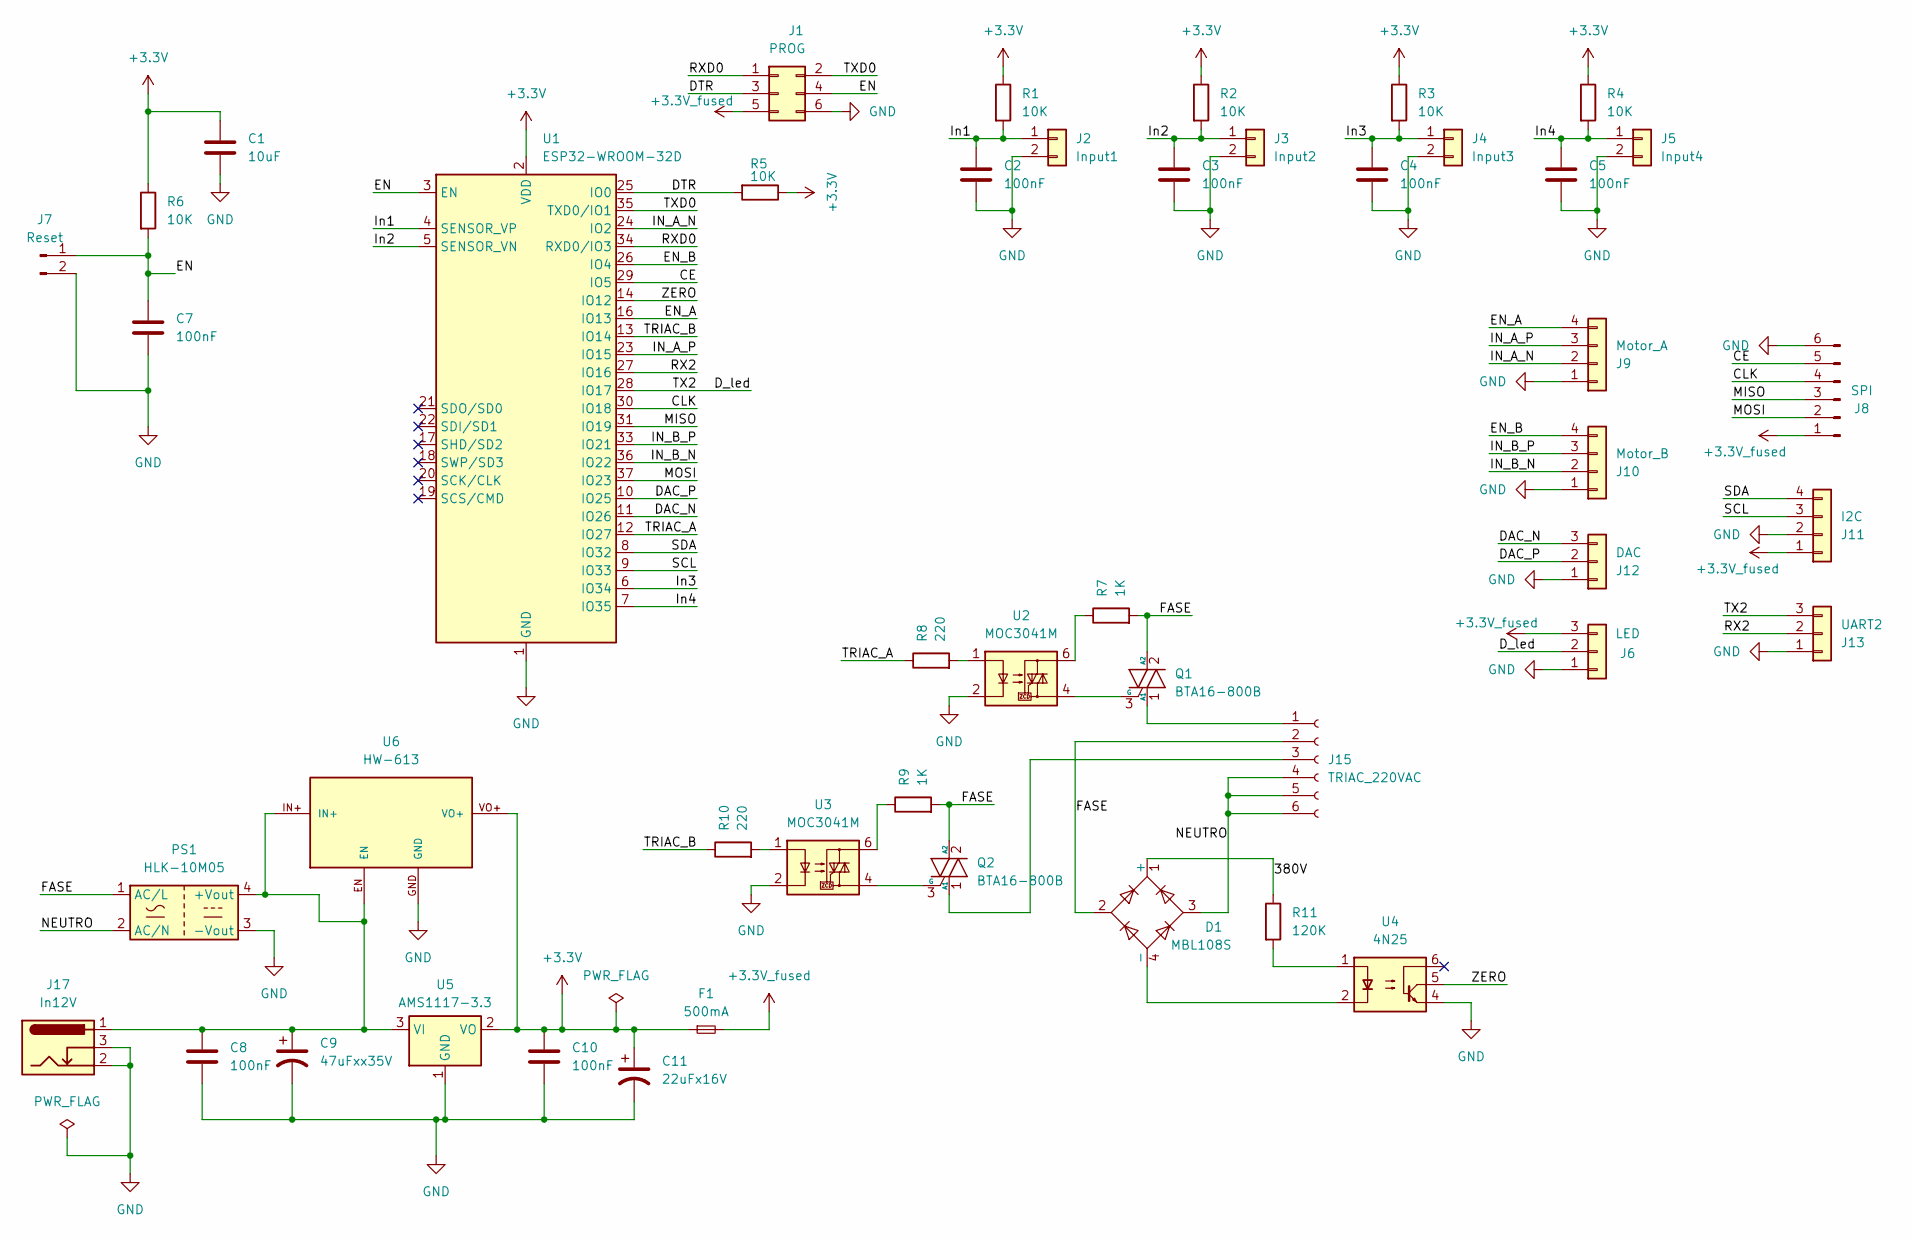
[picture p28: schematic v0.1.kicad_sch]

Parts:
C1: 10uF; C_0805_2012Metric_Pad1.18x1.45mm_HandSolder
C2, C3, C4, C5, C7, C8, C10: 100nF; C_0805_2012Metric_Pad1.18x1.45mm_HandSolder
C9: 47uFxx35V; CP_EIA-6032-28_Kemet-C_Pad2.25x2.35mm_HandSolder
C11: 22uFx16V; CP_EIA-6032-28_Kemet-C_Pad2.25x2.35mm_HandSolder
D1: MBL108S; Diode_Bridge_Vishay_DFS
F1: 500mA; Fuse_1206_3216Metric_Pad1.42x1.75mm_HandSolder
J1: PROG; PinHeader_2x03_P2.54mm_Vertical
J2: Input1; Molex_SL_171971-0002_1x02_P2.54mm_Vertical
J3: Input2; Molex_SL_171971-0002_1x02_P2.54mm_Vertical
J4: Input3; Molex_SL_171971-0002_1x02_P2.54mm_Vertical
J5: Input4; Molex_SL_171971-0002_1x02_P2.54mm_Vertical
J6: LED; Molex_SL_171971-0003_1x03_P2.54mm_Vertical
J7: Reset; PinHeader_1x02_P2.54mm_Vertical
J8: SPI; PinHeader_1x06_P2.54mm_Vertical
J9: Motor_A; Molex_SL_171971-0004_1x04_P2.54mm_Vertical
J10: Motor_B; Molex_SL_171971-0004_1x04_P2.54mm_Vertical
J11: I2C; Molex_SL_171971-0004_1x04_P2.54mm_Vertical
J12: DAC; Molex_SL_171971-0003_1x03_P2.54mm_Vertical
J13: UART2; Molex_SL_171971-0003_1x03_P2.54mm_Vertical
J15: TRIAC_220VAC; Molex_Mini-Fit_Jr_5569-06A2_2x03_P4.20mm_Horizontal
J17: In12V; BarrelJack_Horizontal
PS1: HLK-10M05; Converter_ACDC_Hi-Link_HLK-10Mxx
Q1, Q2: BTA16-800B; TO-220-3_Vertical
R1, R2, R3, R4, R5, R6: 10K; R_0805_2012Metric_Pad1.20x1.40mm_HandSolder
R7, R9: 1K; R_0805_2012Metric_Pad1.20x1.40mm_HandSolder
R8, R10: 220; R_0805_2012Metric_Pad1.20x1.40mm_HandSolder
R11: 120K; R_0805_2012Metric_Pad1.20x1.40mm_HandSolder
U1: ESP32-WROOM-32D
U2, U3: MOC3041M; SMDIP-6_W9.53mm
U4: 4N25; SMDIP-6_W9.53mm
U5: AMS1117-3.3; SOT-223-3_TabPin2
U6: HW-613

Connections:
/380V: D1.1 (+), R11.1; also elsewhere on the board
/CE: J8.5, U1.29 (IO5)
/CLK: J8.4, U1.30 (IO18)
/DAC_N: J12.3, U1.11 (IO26)
/DAC_P: J12.2, U1.10 (IO25)
/DTR: J1.3, R5.2, U1.25 (IO0)
/D_led: J6.2, J13.3, U1.28 (IO17)
/EN: C7.1, J1.4, J7.1, R6.2, U1.3 (EN)
/EN_A: J9.4, U1.16 (IO13)
/EN_B: J10.4, U1.26 (IO4)
/FASE: D1.2, J15.2, PS1.1 (AC/L), Q1.2 (A2), Q2.2 (A2), R7.2, R9.2; also elsewhere on the board
/IN_A_N: J9.2, U1.24 (IO2)
/IN_A_P: J9.3, U1.23 (IO15)
/IN_B_N: J10.2, U1.36 (IO22)
/IN_B_P: J10.3, U1.33 (IO21)
/In1: C2.1, J2.1, R1.2, U1.4 (SENSOR_VP)
/In2: C3.1, J3.1, R2.2, U1.5 (SENSOR_VN)
/In3: C4.1, J4.1, R3.2, U1.6 (IO34)
/In4: C5.1, J5.1, R4.2, U1.7 (IO35)
/MISO: J8.3, U1.31 (IO19)
/MOSI: J8.2, U1.37 (IO23)
/NEUTRO: D1.3, J15.4, J15.5, J15.6, PS1.2 (AC/N); also elsewhere on the board
/RX2: J13.2, U1.27 (IO16)
/RXD0: J1.1, U1.34 (RXD0/IO3)
/SCL: J11.3, U1.9 (IO33)
/SDA: J11.4, U1.8 (IO32)
/TRIAC_A: R8.1, U1.12 (IO27)
/TRIAC_B: R10.1, U1.13 (IO14)
/TXD0: J1.2, U1.35 (TXD0/IO1)
/ZERO: U1.14 (IO12), U4.5
GND: C1.2, C2.2, C3.2, C4.2, C5.2, C7.2, C8.2, C9.2, C10.2, C11.2, J1.6, J2.2, J3.2, J4.2, J5.2, J6.1, J7.2, J8.6, J9.1, J10.1, J11.2, J12.1, J13.1, J17.2, J17.3, PS1.3 (-Vout), U1.1 (GND), U1.15 (GND), U1.38 (GND), U1.39 (GND), U2.2, U3.2, U4.4, U5.1 (GND), U6.GND
unnamed 31: D1.4 (-), U4.2; also elsewhere on the board
unnamed: J15.1, Q1.1 (A1)
unnamed: J15.3, Q2.1 (A1)
unnamed: C8.1, C9.1, J17.1, PS1.4 (+Vout), U5.3 (VI), U6.EN, U6.IN+
unnamed: Q1.3 (G), U2.4
unnamed: Q2.3 (G), U3.4
unnamed: R7.1, U2.6
unnamed: R8.2, U2.1
unnamed: R9.1, U3.6
unnamed: R10.2, U3.1
unnamed: R11.2, U4.1

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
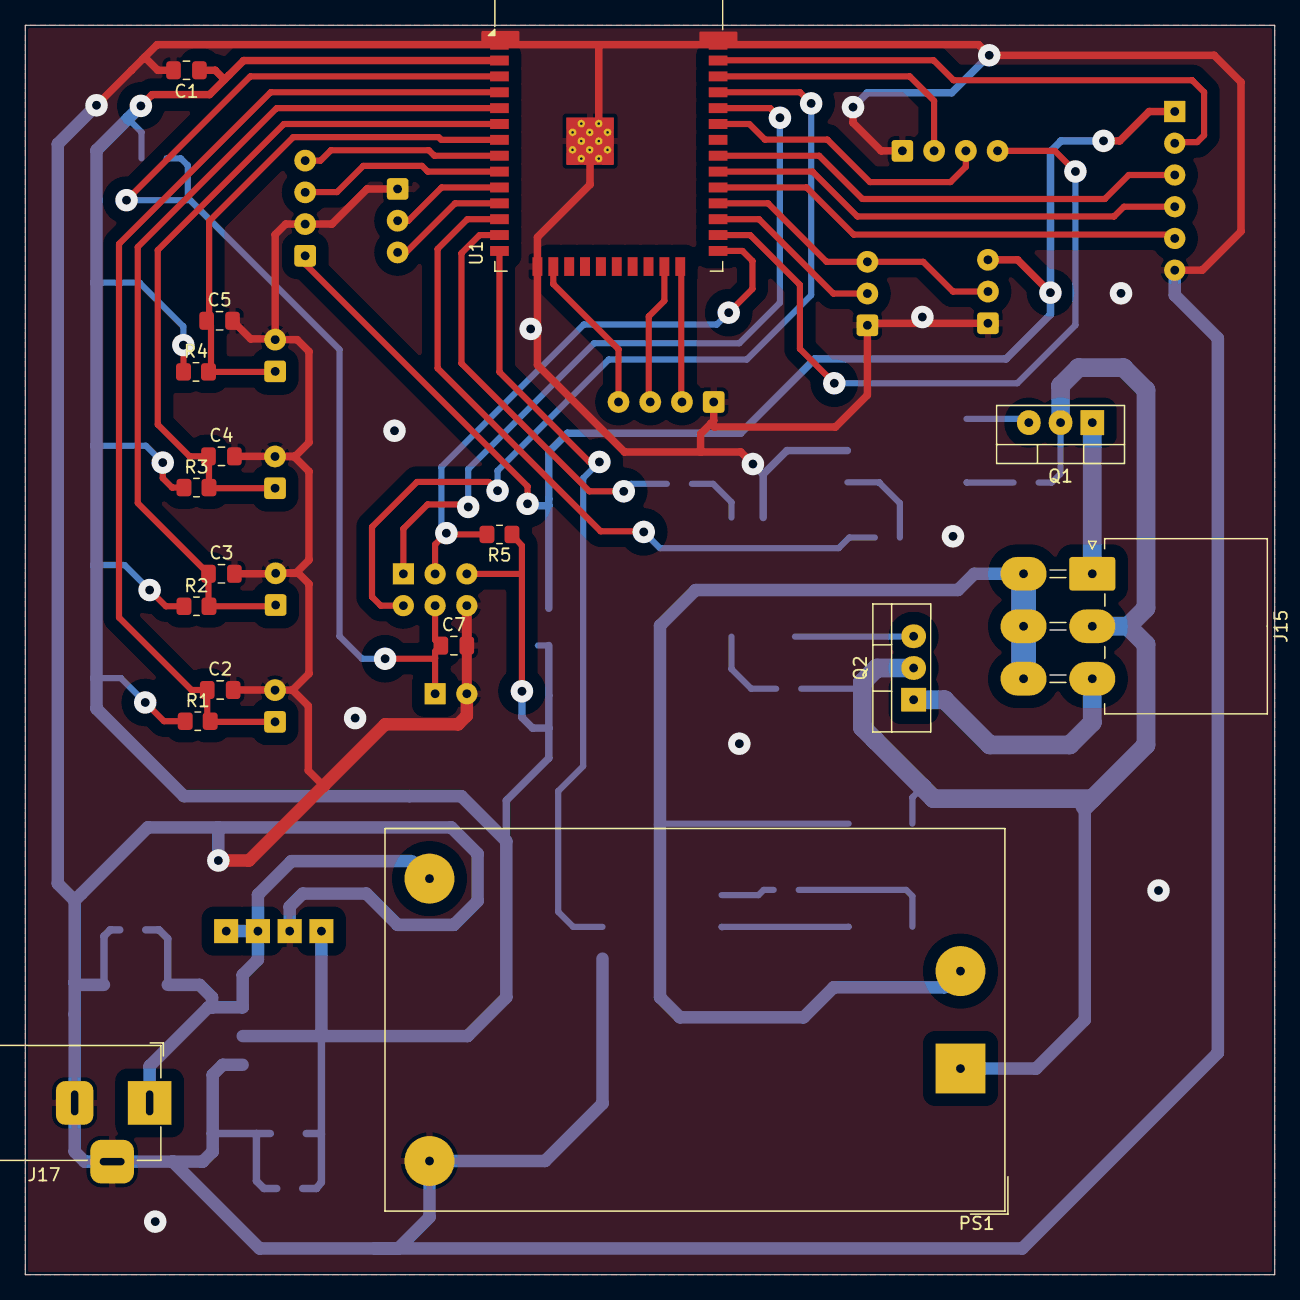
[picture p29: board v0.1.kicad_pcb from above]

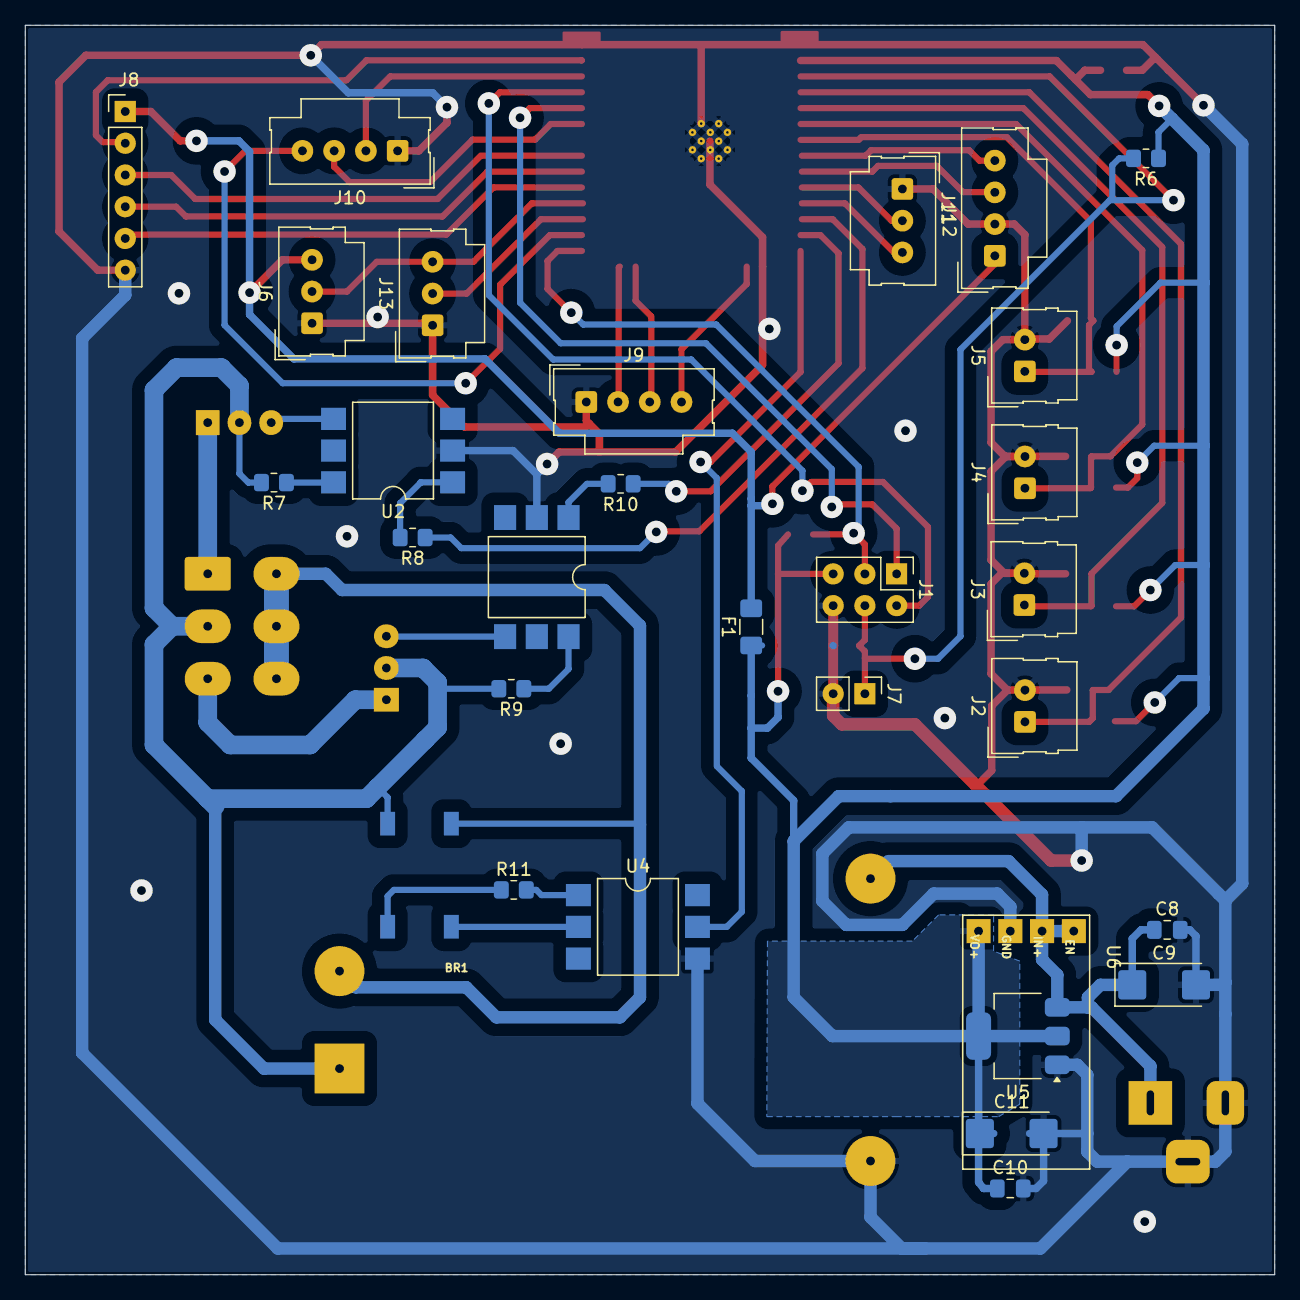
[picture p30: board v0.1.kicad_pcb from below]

Board: 2 copper layers, 100.0 x 100.0 mm, 47 parts (30 on the bottom side), 44 nets.

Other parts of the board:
BR1: DB107S; DIOB_DB107S

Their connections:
/380V: BR1.+; also elsewhere on the board
/FASE: BR1.AC1; also elsewhere on the board
/NEUTRO: BR1.AC2; also elsewhere on the board
unnamed 31: BR1.-; also elsewhere on the board

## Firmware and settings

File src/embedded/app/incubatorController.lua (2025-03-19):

-- SPDX-FileCopyrightText: 2025 info@altermundi.net
--
-- SPDX-License-Identifier: AGPL-3.0-only

---@diagnostic disable: lowercase-global

-----------------------------------------------------------------------------
--  This is the reference implementation to train lua fucntions. It
--  implements part of the core functionality and has some incomplete comments.
--
--  javier jorge
--
--  License:
-----------------------------------------------------------------------------
require("credentials")
require("SendToGrafana")
incubator = require("incubator")
apiserver = require("restapi")
deque = require ('deque')
log = require ('log')
configurator = require('configurator')

--log.level = "debug"
--log.usecolor=false


--holds the last 10 values
local last_temps_queue = deque.new()

controlervars = {
    rotation_enabled=true,
    rotation_activated = false,
    downtime = 0,
    uptime = 0,
    demora = 0,
    half = 0
}
-----------------------------------------------------------------------------------
-- ! @function is_temp_changing 	     verifies if temperature is changing
-- ! @param temperature						 actual temperature
------------------------------------------------------------------------------------
function is_temp_changing(temperature)
    last_temps_queue:push_right(temperature)
    if last_temps_queue:length() < 10 then
        ---les than 9 elements in the queue
        return true
    end
    if last_temps_queue:length() > 10 then
        -- remove one item
        last_temps_queue:pop_left()
    end
    local vant = nil

    for i, v in ipairs(last_temps_queue:contents()) do
        log.trace("[T] val:", i, v, vant)
        if vant ~= nil and vant ~= v then
            --everything is fine...
            return true
        end
        vant = v
    end
    --temp is not changing
    return false
end

-----------------------------------------------------------------------------------
-- ! @function temp_control 	     handles temperature control
-- ! @param temperature						 overall temperature
-- ! @param min_temp 							 temperature at which the resistor turns on
-- ! @param,max_temp 							 temperature at which the resistor turns off
------------------------------------------------------------------------------------

temp_history = {0, 0, 0, 0, 0}
resistor_on_counter = 0
resistor_on_tmp = 0
resistor_on_derivative = 0  -- Store first derivative when heater was turned ON
low_derivative_count = 0

function first_precise_centered_derivative()
    -- f'(t) = (-T[n+2] + 8T[n+1] - 8T[n-1] + T[n-2]) / 12
    return (-temp_history[5] + 8 * temp_history[4] - 8 * temp_history[2] + temp_history[1]) / 12
end

function temp_control(temperature, min_temp, max_temp)

    -- Smooth temperature
    smooth_temp = ( temp_history[4]+ temp_history[5]+ temperature) / 3

    temp_history[1] = temp_history[2]
    temp_history[2] = temp_history[3]
    temp_history[3] = temp_history[4]
    temp_history[4] = temp_history[5]
    temp_history[5] = smooth_temp

    -- Compute derivatives
    local temp_rate = first_precise_centered_derivative()

    log.trace("[T] temp " .. temperature .. " min:" .. min_temp .. " max:" .. max_temp ..
              " count " .. resistor_on_counter .. " resistor on temp " .. resistor_on_tmp..
              " temp_rate " .. temp_rate)

    if resistor_on_counter == 0 then
        resistor_on_tmp = temperature
        resistor_on_derivative = temp_rate  -- Store first derivative when heater was turned ON
    end


    -- Check if the temperature is increasing effectively
    local tolerance = 0.002  -- Small tolerance to allow minor fluctuations
    local low_derivative_limit = 3  -- Require up to 3 consecutive low values before triggering an error
        
    if resistor_on_counter == 30 then

        if temperature > max_temp + 4 then
            log.addError("temperature", "[T] temperature too high: " .. temperature)
        else if temperature < min_temp - 4 then
            log.addError("temperature", "[T] temperature too low: " .. temperature)
        end
        
        if temp_rate > (resistor_on_derivative - tolerance) then
            log.trace("[T] temperature is increasing properly !!!!!")
            low_derivative_count = 0  -- Reset the counter if temperature is increasing
        else
            low_derivative_count = low_derivative_count + 1
            if low_derivative_count >= low_derivative_limit then
                log.addError("temperature", "[T] temperature is not increasing enough.. derivative: " ..
                             temp_rate .. " < " .. resistor_on_derivative)
                low_derivative_count = 0  -- Reset after logging the error
            end
        end
        resistor_on_counter = -1 --if resistor is "on" it wont be 0 next time.
    end

    if incubator.resistor then
        resistor_on_counter=resistor_on_counter+1
    else
        resistor_on_counter=0
    end

    if temperature <= min_temp then
        if is_temp_changing(temperature) then
            log.trace("[T] temperature is changing")
            log.trace("[T] turn resistor on")
            incubator.heater(true)
        else
            log.addError("temperature","[T] temperature is not changing")
            log.trace("[T] turn resistor off")
            incubator.heater(false)
        end
    elseif temperature >= max_temp then
        incubator.heater(false)
        log.trace("[T] turn resistor off")
    end -- end if
end     -- end function
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

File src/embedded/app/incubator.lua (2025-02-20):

-- Copyright (C) 2023  Asociación Civil Altermundi <info@altermundi.net>
-- Copyright (c) 2023  Instituto Nacional de Tecnología Industrial
-- Copyright (c) 2023  Javier Jorge <jjorge@inti.gob.ar>
-- SPDX-FileCopyrightText: 2025 info@altermundi.net
--
-- SPDX-License-Identifier: AGPL-3.0-only

-----------------------------------------------------------------------------
credentials = require('credentials')

local M = {
	name                            = ..., -- module name, upvalue from require('module-name')
	model                           = nil, -- M model:
	resistor                        = false,
	humidifier                      = false,
	rotation                        = false,
	temperature                     = 99.9, -- integer value of temperature [0.01 C]
	pressure                        = 0, -- integer value of preassure [Pa]=[0.01 hPa]
	humidity                        = 0, -- integer value of rel.humidity [0.01 %]
	is_testing                      = false,
	max_temp                        = 37.7,
	min_temp                        = 37.5,
	is_sensorok                     = false,
	is_simulate_temp_local          = false,
	rotation_switch_deactivate_time = 10000, -- max amount of time the sensor is down when the incubator is moving in ms
	rotation_duration               = 50000, -- max amount of time the rotation should last in ms
	rotation_period                 = 3600000, -- time in ms
	humidifier_enabled              = true,
	max_hum                         = 100,
	min_hum                         = 1,
	humidifier_max_on_time          = 2, -- sec !! 
	humidifier_off_time             = 120, -- sec !! 
	hum_turn_on_time                = 0,
	hum_turn_off_time               = 0,
	tray_one_date = 0,
	tray_two_date = 0,
	tray_three_date = 0,
	incubation_period = 18,
	hash = 1235,
	incubator_name = string.format("incu-%s",wifi.sta.getmac()),
	rotate_up                       = true,
	rotation_enabled				= true,
    rotation_activated 				= false
}

_G[M.name] = M

local sensor = require('bme280')

function M.startbme()
	if sensor.init(GPIOBMESDA, GPIOBMESCL, true) then
		M.is_sensorok = true
	else
		M.is_sensorok = false
	end
end

function M.init_values()
	M.startbme()
	gpio.config({ gpio = { GPIORESISTOR, GPIOVOLTEO_UP, GPIOVOLTEO_DOWN, GPIOHUMID, GPIOVOLTEO_EN }, dir = gpio.OUT })
	-- config inputs
	gpio.config({ gpio = { GPIOREEDS_DOWN, GPIOREEDS_UP }, dir = gpio.IN, pull = gpio.PULL_UP })

	gpio.set_drive(GPIOVOLTEO_UP, gpio.DRIVE_3)
	gpio.set_drive(GPIOVOLTEO_DOWN, gpio.DRIVE_3)
	gpio.set_drive(GPIOHUMID, gpio.DRIVE_3)
	gpio.set_drive(GPIORESISTOR, gpio.DRIVE_3)
	gpio.set_drive(GPIOVOLTEO_EN, gpio.DRIVE_3)



	gpio.write(GPIOVOLTEO_UP, 0)
	gpio.write(GPIOVOLTEO_DOWN, 0)
	gpio.write(GPIOHUMID, 1)
	gpio.write(GPIORESISTOR, 0)
	gpio.write(GPIOVOLTEO_EN, 0)
end -- end function

-------------------------------------
-- @function enable_testing 	Enables testing mode asserting correct M funcioning
--
-- @param min 								is equal to the minimum temperature to test
-- @param max 								is equal to the maximum temperature to test
-------------------------------------
function M.enable_testing(simulatetemp)
	M.is_testing = true;
	M.is_simulate_temp_local = simulatetemp
end --end function

-------------------------------------
-- simulates a change in sensors acording to actuators and returns sensor readings
--
-- @returns temperature, humidity, pressure
-------------------------------------
function M.get_values()
	if M.is_simulate_temp_local then
		if M.resistor then
			M.temperature = (M.temperature + 1)
		else
			M.temperature = (M.temperature - math.random(1, 15))
		end --end if

		if M.humidifier then
			M.humidity = (M.humidity + 1)
		else
			M.humidity = (M.humidity - math.random(1, 4))
		end --end if
	else
		M.startbme()
		if M.is_sensorok then
			sensor.read()
			if (sensor.temperature / 100) < -40 or (sensor.temperature / 100) > 86 then
				M.temperature = 99.9
				M.humidity = 99.9
				M.pressure = 99.9
				log.addError("temperature","temperature is out of range T:"..sensor.temperature / 100 )
				--try to restart bme
			else
				M.temperature = (sensor.temperature / 100)
				M.humidity = (sensor.humidity / 100)
				M.pressure = (sensor.pressure / 100)
			end
		else
			M.temperature = 99.9
			M.humidity = 99.9
			M.pressure = 99.9
			log.addError("sensors","Failed to start bme, Please check the cables and connections.")
		end -- end if
	end --if end

	return M.temperature, M.humidity, M.pressure
end --end function

-------------------------------------
-- @function heater 					Activates or deactivates heater
--
-- @param status "true" 			increments temperature, "false" temp "decrements"
-------------------------------------
function M.heater(status --[[bool]])
	M.resistor = status
	if status then
		gpio.write(GPIORESISTOR, 1)
	else
		gpio.write(GPIORESISTOR, 0)
	end
	M.assert_conditions()
end --end function

function M.assert_conditions()
	log.trace("temp actual ", M.temperature, ", max ", M.max_temp, ",min ", M.min_temp, ",resitor status ", M.resistor)
	if M.is_testing then
		if (M.temperature > M.max_temp and M.resistor) then
			log.addError("temperature","temperature > max_temp and resistor is on")
			--assert(not M.resistor)
		end --if end
		if (M.temperature < M.min_temp and not M.resistor) then
			log.addError("temperature","temperature < M.min_temp and resistor is off")
			--assert(M.resistor)
		end --if end
	end -- if is_testing
end   --end fucition

function M.get_uptime_in_sec()
	local high_bytes, _ = node.uptime()
	return tonumber((high_bytes / 1000000))
end
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

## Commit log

2024-05-04 Add humidifier STL files
    [caja_protectora_humidificador.stl, estructura_principal_humidificador.stl, soporte_humidificador.stl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]
2024-05-31 configurations view shows the elapsed time since the tray buttons were pressed
2024-06-07 Add Tubo_Humidificador.stl
    [Tubo_humidificador.stl]
2024-06-25 the buttons keep their colors Fixes #52
2024-07-10 Add binaries for ESP32-CAM
2024-07-15 placa Olivia v0.1 esquematico
    [v0.1.kicad_pcb, v0.1.kicad_sch]
2024-07-17 pcb primer borrador
    [v0.1.kicad_pcb, v0.1.kicad_sch]
2024-07-17 pcb primera version
    [v0.1.kicad_pcb, v0.1.kicad_sch]
2024-07-18 pcb fix Io0 pull-up
    [v0.1.kicad_pcb, v0.1.kicad_sch]
2024-07-18 minor fix routing
    [v0.1.kicad_pcb]
2024-07-19 various fix. Traces:0,5. Clearance:1,0
    [v0.1.kicad_pcb, v0.1.kicad_sch]
2024-07-19 reduce esp pad size
    [v0.1.kicad_pcb]
2024-07-20 minor fix
    [v0.1.kicad_pcb]
2024-07-29 Revert "Test Fabri Config"
    This reverts commit b485b1999be309a7c12906e24227fa8b9d2a6b47.
    [incubator.lua, incubatorController.lua]
2024-07-31 fix pin number and inicializations
    [incubator.lua]
2024-08-05 adds ods test reference
    [testcases humedad.ods]
2024-09-03 Replace prints for logs and logs only send if is type error
    [SendToGrafana.lua, incubatorController.lua]
2024-09-05 Fix API and some minor bugs
    [incubator.lua]
2024-09-19 minor fixes
    [v0.1.kicad_pcb]
2024-09-19 Smaller more compact layout with AC restriction zone.
    [v0.2.kicad_pcb, v0.2.kicad_sch]
2024-10-03 volteo 2.0.1
2024-10-07 fixes rotation initiation when sensor is active
    [incubatorController.lua]
2024-10-11 f_rotation: improves messages and prevents noisi activations
    [incubator.lua, incubatorController.lua]
2024-10-22 Fix TDD and incubator
    [incubator.lua]
2024-10-25 rotation STL files added
    [CarcasaPolea_conColumnas.stl, SoporteMotorConTriangulos.stl, SoportePoleaNuevo.stl]
2024-11-06 Fix Incubator name with MAC
    [incubator.lua]
2024-11-07 improves rotation failure detection
    [incubator.lua, incubatorController.lua]
2024-11-07 Update incubatorController.lua
    do not disable rotation unless one of the sensors is down
2024-11-13 Update incubatorController.lua
    Deshacer comentario de los timers
2024-11-15 fixes after real tests
    [incubator.lua]
2024-11-28 agregado de lista de componentes de incubadora
    [Despiece Incubadora.ods]
2024-12-01 Remuevo carpetas de otras placas
    Retiro del repo las carpetas de los prototipos anteriores
    [DCM y ULTRASONIDO 1.3 .SchDoc, INCUBA 1.3.PrjPcb, INCUBA 1.3.SchDoc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]
2024-12-01 Create esquemaLibreIncu
    Genero el archivo con algunos componentes del esquema eléctrico
2024-12-02 Actualizo con mejoras el esquema
2024-12-02 Más mejoras en el esquema
2024-12-02 add equal symbol missing
    [incubator.lua]
2024-12-06 only wait for a sensor if a sensor was on...
2025-01-07 remove unwated error messages, change them for a warning
    [incubator.lua]
2025-01-10 fix resitor initial value
    [incubator.lua]
2025-01-10 refactor logging mechanism to use log.addError for error handling; improve error tracking for temperature, humidity, rotation, and WiFi issues
    [incubator.lua, incubatorController.lua]
2025-01-11 refactor error logging in temperature and humidity controls; improve alert messages and formatting
    [incubator.lua, incubatorController.lua]
2025-01-11 remove Grafana alerts, add time stamp to error message
    [incubatorController.lua]
2025-01-11 fix: correct formatting in temperature logging and adjust alert cycle count
    [incubatorController.lua]
2025-01-11 refactor: replace Grafana alerts with log.addError for temperature condition checks
    [incubator.lua]
2025-01-11 reset resistor counter and improve error text
    [incubator.lua, incubatorController.lua]
2025-01-11 simplify and make more deterministic resistor and humidity control logic; improve error logging
    [incubatorController.lua]
2025-01-11 fix: adjust temperature threshold for resistor alarm, temperature changes are really slow
    [incubatorController.lua]
2025-01-29 fix timer inicialization error in incubatorController.lua
    [34m[TRACE 2025-01-29 12:48:15 DST:0] [0m : Sending data to Grafana
    [34m[TRACE 2025-01-29 12:48:15 DST:0] [0m : [R] Setting rotation duration to 66266.1
    incubatorController.lua:315: bad argument #1 to 'register' (Range: 1-6870947)
    stack traceback:
    [C]: in function 'register'
    incubatorController.lua:315: in function <incubatorController.lua:294>
    [incubatorController.lua]
2025-02-02 functioning manual rotation buttons
2025-02-03 Update incubator.lua
    fix time between successive humidifier turn on
    [incubator.lua]
2025-02-04 fix initial temp problem
    [incubator.lua]
2025-02-05 prevent false positves in temp changes
    [incubatorController.lua]
2025-02-05 mejoras en el esquema eléctrico
2025-03-14 final 3d models for rotation
    [Polea.stl, SoporteMotor.stl, SoportePolea.stl]
2025-03-19 fix multiple false positives at start
    [incubatorController.lua]
2025-03-19 add temperature to low
